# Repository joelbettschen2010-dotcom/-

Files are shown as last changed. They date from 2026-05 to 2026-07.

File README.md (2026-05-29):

# 🚲 Velo Navi Schweiz

Eine Velo-/E-Bike-Navigations-App für die **ganze Schweiz**. Sie schlägt
mehrere Routen vor, berechnet die Fahrzeit **physikalisch** (inkl. Steigung
und Velo-Typ) und **lernt dein persönliches Tempo** aus deinem Feedback nach
jeder Fahrt.

Läuft als **einzelne Web-App ohne Server** – einfach `index.html` im Browser
öffnen (oder in der Claude-App als Vorschau).

## Funktionen

- **Ganze Schweiz** – Ortssuche über swisstopo/geo.admin.ch oder Klick auf die Karte.
- **Mehrere Routenvorschläge** – Alternativrouten + optional andere Fahrstile als Varianten.
- **Velo-Typ wählbar** – **Velo**, **E-Bike 25** (Abregelung 25 km/h),
  **E-Bike 45** (S-Pedelec, 45 km/h). Der Motor wird im Zeitmodell berücksichtigt.
- **Routen-Stil** – **Trekking/Stadt**, **Rennvelo**, **Gravel**, **MTB Trail**
  (eigene BRouter-Profile mit passenden Untergründen).
- **Höhenberechnung** – die Steigung jedes Streckenabschnitts fliesst in die Zeit ein
  (bergauf dauert länger, bergab schneller), mit Höhenprofil-Diagramm.
- **Routenbeschreibung** – Anteil Strasse / Veloweg / Schotter / Wald / Trail,
  Höhenmeter ↑↓ und maximale Steigung pro Route.
- **Tempo-Feedback & Kalibrierung** – nach jeder Fahrt angeben „war schneller/langsamer".
  Die App passt den Tempo-Faktor **pro Velo-Typ** an und speichert ihn lokal.
- **GPX-Export** je Route.

## Bedienung

1. `index.html` im Browser öffnen.
2. Start & Ziel eingeben (Suche) oder auf die Karte klicken.
3. Velo-Typ, Routen-Stil und Tretleistung wählen.
4. **Routen berechnen** drücken.
5. Eine Route anklicken → Karte + Höhenprofil. Mit **🏁 Gefahren** Feedback geben.

## Wie die Zeit berechnet wird

Pro Streckenabschnitt wird die Gleichgewichts­geschwindigkeit aus der
Leistungs­gleichung gelöst:

```
P = v · ( Crr·m·g·cosθ  +  m·g·sinθ  +  ½·ρ·CdA·v² ) / η
```

- `Crr` Rollwiderstand (je nach Untergrund: Asphalt … Trail)
- `m` Gesamtmasse (Fahrer + Velo, je nach Velo-Typ)
- `θ` Steigungswinkel aus den Höhendaten
- `CdA` Luftwiderstandsfläche, `ρ` Luftdichte, `η` Antriebs­wirkungsgrad
- `P` = Tretleistung **+ Motorleistung** (E-Bike, nur unterhalb der Abregelgeschwindigkeit)

Das Ergebnis wird mit deinem persönlichen **Kalibrierungs­faktor** multipliziert.

## Datenquellen

- **Karten:** [swisstopo](https://www.swisstopo.admin.ch) WMTS (Landeskarte / Satellit)
- **Routing & Höhen:** [BRouter](https://brouter.de) (OSM-basiert, kostenlos)
- **Ortssuche:** geo.admin.ch SearchServer
- **Karten-Engine:** [Leaflet](https://leafletjs.com)

Alle Dienste sind kostenlos und benötigen keinen API-Schlüssel. Es ist eine
Internet­verbindung nötig (Kacheln, Routing, Suche).

## Dateien

| Datei | Zweck |
|---|---|
| `index.html` | Aufbau / UI |
| `style.css` | Gestaltung (dunkles Theme, responsiv) |
| `app.js` | Karte, Routing, Zeitmodell, Höhenprofil, Feedback |

## Hinweise / Limiten

- Der öffentliche BRouter-Server hat eine Fair-Use-Begrenzung.
- Die berechnete Zeit ist eine Schätzung ohne Pausen; mit Feedback wird sie genauer.
- E-Bike-Reichweite/Akku wird (noch) nicht modelliert.

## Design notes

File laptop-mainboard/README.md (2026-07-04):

# Laptop-Mainboard — AMD AM5 im HP-EliteBook-850-G7-Chassis (Rev B)

Komplettes KiCad-8-Projekt für ein Laptop-Mainboard mit **gesockelter**
Desktop-CPU (AM5) statt verlöteter Mobile-CPU.

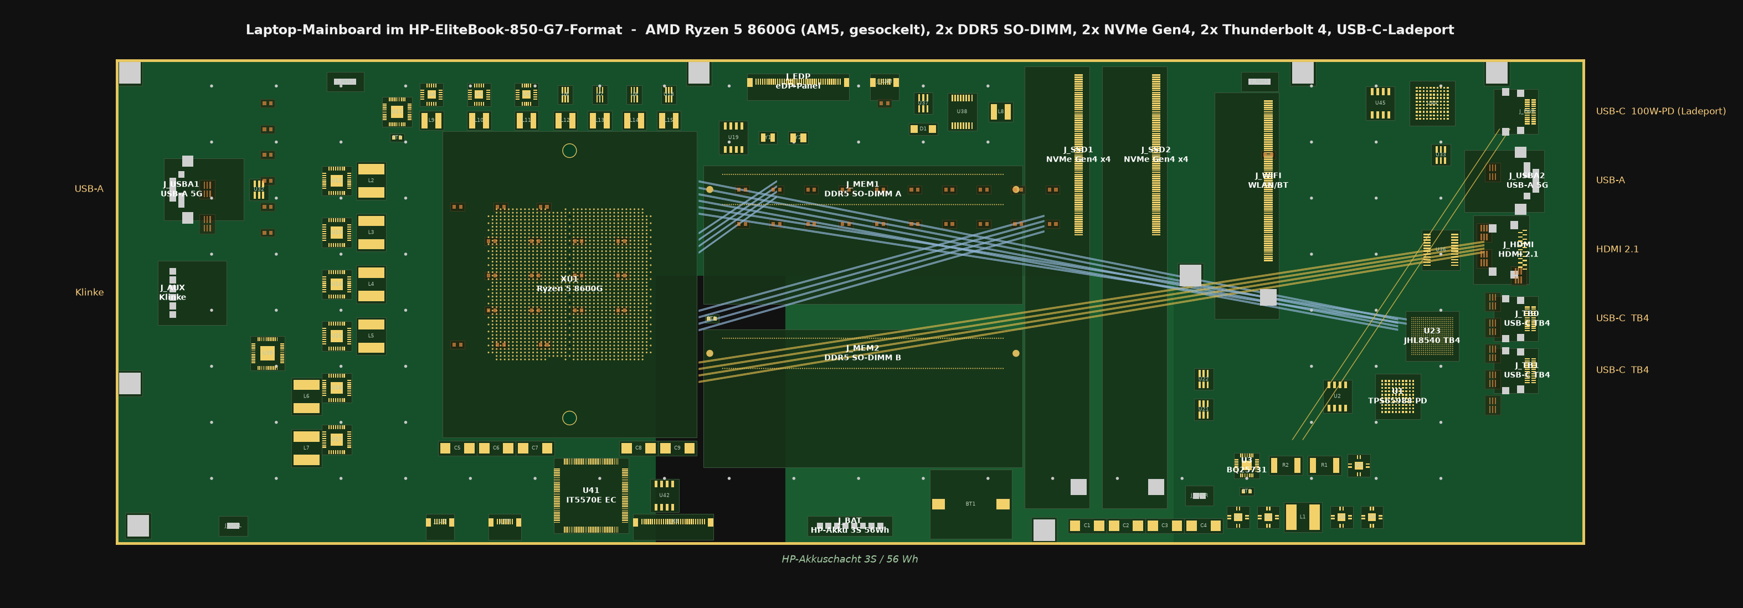
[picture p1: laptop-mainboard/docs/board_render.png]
Board


Konzept

## Eckdaten

| Bereich | Umsetzung |
|---|---|
| CPU | **AMD Ryzen 5 8600G** (x86-64, Zen 4, 6C/12T, Radeon 760M) im **AM5-Sockel LGA-1718** — wechselbar wie beim Desktop-PC, per cTDP auf 35–45 W gedrosselt |
| Chipsatz | **keiner** (chipsatzlos wie DeskMini X600) — alle I/O direkt vom SoC |
| Pinbelegung | **alle 1718 AM5-Pins benannt** (docs/am5_pinmap.csv, WikiChip/Wikimedia Public Domain); 1708 Sockelpads im Board mit echtem Signal-Netz |
| RAM | 2× DDR5 **SO-DIMM** (1 DIMM pro Kanal, bis DDR5-5600, max. 96 GB) |
| Storage | 2× **M.2 2280 NVMe**, je PCIe 4.0 ×4, getrennt schaltbare 3.3-V-Schienen |
| WLAN | 1× M.2 2230 E-Key (PCIe ×1 + USB 2.0), z. B. Wi-Fi 7 Modul |
| Thunderbolt | 2× **Thunderbolt 4** über **Intel JHL8540** (Maple Ridge), PCIe ×4 Uplink + 2× DP-1.4-Sink |
| Laden | **Eigener USB-C-Ladeport** (100 W USB-PD, TPS65987D) an der Barrel-Jack-Position → **BQ25731** → HP-Akku 3S/56 Wh (NVDC) |
| USB | 2× USB-A 5 Gbit (je einer links/rechts, wie 850 G7) |
| Netzwerk | WLAN/BT über M.2-Modul (das Original hat kein RJ45) |
| Video | HDMI 2.1 (nativ vom SoC, TPD12S016-Companion), intern eDP 1.4 (2 Lanes) |
| Audio | Realtek ALC256, 3.5-mm-Kombiklinke (AUX), 2× 2-W-Lautsprecher |
| Kleinteile | Blatt 10: MLCC-Bänke, 11 ESD-Arrays, USB2-Chokes, Straps (beidseitige Bestückung) |
| EC | ITE IT5570E: Power-Sequencing, Tastatur 8×18, Akku-SMBus, 2× Lüfter |
| Board | 340 × 112 mm, 8 Lagen, Portlayout/Umriss für HP EliteBook 850 G7 (docs/elitebook.md) |

## Projektstruktur

```
laptop-mainboard/
├── kicad/                     KiCad-8-Projekt (öffnen: laptop-mainboard.kicad_pro)
│   ├── laptop-mainboard.kicad_sch   Übersichtsblatt (Hierarchie)
│   ├── 01_power_pd.kicad_sch        USB-PD, Laderegler, Systemschienen
│   ├── 02_vrm_cpu.kicad_sch         CPU-VRM (SVI3, 4+2 Phasen)
│   ├── 03_cpu_am5.kicad_sch         AM5-Sockel, BIOS-Flash, RTC
│   ├── 04_memory.kicad_sch          2× DDR5 SO-DIMM
│   ├── 05_storage.kicad_sch         2× M.2 NVMe + WLAN
│   ├── 06_usb_tb4.kicad_sch         Thunderbolt 4 + USB
│   ├── 07_ladeport.kicad_sch        USB-C-Ladeport 100W (TPS65987D)
│   ├── 08_display.kicad_sch         eDP, HDMI, Backlight, Webcam
│   ├── 09_audio_sd_ec.kicad_sch     Audio, Embedded Controller
│   ├── 10_kleinteile.kicad_sch      Entkopplung, ESD, Filter, Straps
│   ├── laptop-mainboard.kicad_pcb   Board: Umriss, Platzierung, Lagen, Zonen
│   ├── lm.kicad_sym                 Symbolbibliothek
│   └── laptop_mainboard.pretty/     Footprints (inkl. LGA-1718, SO-DIMM 262)
├── docs/
│   ├── architektur.md         Blockdiagramm, PCIe-/USB-/Display-Budget
│   ├── power.md               Schienen, Power-Budget, Sequencing
│   ├── layout.md              Lagenaufbau, Floorplan, Routing-Regeln
│   ├── elitebook.md           EliteBook-850-G7-Einbau: passt/zu messen
│   ├── am5_pinmap.csv         Alle 1718 AM5-Pins mit Signalnamen
│   ├── grenzen.md             Was dieses Projekt (bewusst) nicht abdeckt
│   ├── board_render.png       Bestückungsansicht (generiert)
│   └── bom.csv                Stückliste (150 Positionen)
└── tools/
    └── gen_all.py             Generator — erzeugt alle KiCad-Dateien
```

**Wichtig:** Die KiCad-Dateien werden generiert. Änderungen in
`tools/kicadgen/boarddata*.py` (Schaltung) bzw. `tools/gen_all.py`
(Floorplan) vornehmen und `python3 tools/gen_all.py` ausführen.

## Warum diese Architektur?

- **Gesockelte CPU:** AMD verkauft Mobile-CPUs nur als BGA (verlötet). Der
  Wunsch „normaler PC-Sockel statt löten" führt zwingend zum Desktop-Sockel
  AM5. Der Ryzen 5 8600G ist die effizienteste AM5-Wahl: monolithischer
  Phoenix-Die (kein Chiplet-Idle-Verbrauch), starke iGPU, offizieller
  cTDP-Bereich 35–65 W.
- **Chipsatzlos:** Ein B650-Chipsatz würde ~7 W dauerhaft verbrauchen. Der
  8600G hat genug eigene Lanes/USB-Ports für alle geforderten Anschlüsse.
- **Echtes Thunderbolt 4:** AMD kann nur USB4. Für zertifizierbares TB4 sitzt
  ein Intel JHL8540 auf dem Board (PCIe ×4 + 2× DisplayPort vom SoC).
- **NVDC-Laden:** Der BQ25731 lässt das System direkt aus dem 100-W-Netzteil
  laufen und lädt den Akku mit dem Rest — Standard-Topologie moderner Laptops.

## Ehrlichkeit / Reifegrad

Rev B ist ein **weit ausgearbeiteter Prototyp-Stand**: vollständige
Systemarchitektur, echte AM5-Pinbelegung (Public-Domain-Quelle) an allen
Sockelpads, Kleinteile (Entkopplung/ESD/Filter) auf eigenem Blatt,
kollisionsfreier beidseitiger Floorplan im EliteBook-Format mit Zonen,
Stitching-Vias und Routing-Korridoren. **Noch nicht bestellbar:** das
DRC-saubere Feinrouting aller ~640 Netze, die Verifikation der
Community-Pinmap und die HP-Mechanik-/FPC-Vermessung stehen aus —
Details in [docs/grenzen.md](docs/grenzen.md) und
[docs/elitebook.md](docs/elitebook.md).

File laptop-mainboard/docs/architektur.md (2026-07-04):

# Systemarchitektur

## Blockdiagramm

```mermaid
flowchart LR
    subgraph SOC["Ryzen 5 8600G (AM5-Sockel)"]
        CPU[Zen4 6C/12T]
        GPU[Radeon 760M]
        IO[SoC-I/O]
    end

    MEM1[SO-DIMM A DDR5] ---|Kanal A| SOC
    MEM2[SO-DIMM B DDR5] ---|Kanal B| SOC

    SOC ---|PCIe4 x4 P0| SSD1[M.2 NVMe 1]
    SOC ---|PCIe4 x4 P1| SSD2[M.2 NVMe 2]
    SOC ---|PCIe3 x4 P2 + 2x DP1.4| TB[JHL8540 TB4]
    TB --- TB0[USB-C TB4 #0]
    TB --- TB1[USB-C TB4 #1]
    SOC ---|PCIe x1 G2 + USB2| WIFI[M.2 E-Key WLAN]
    SOC ---|USB3 Gen1 x2| USBA[2x USB-A]
    SOC ---|HDMI 2.1| HDMI[HDMI-Buchse]
    SOC ---|eDP 1.4 2L| PANEL[15.6 Panel]
    SOC ---|HDA| AUD[ALC256] --- JACK[3.5mm AUX]
    SOC ---|eSPI| EC[IT5570E EC]
    PWR[USB-C-Ladeport 100W] --- PD2[TPS65987D]
    PD2 ---|+VBUS 20V| CHG[BQ25731 Lader] --- BAT[HP-Akku 3S 56Wh]
    PD[TPS65988] --- TB0
    PD --- TB1
    CHG ---|+VSYS| VRM[VRM 4+2 Phasen SVI3] --- SOC
```

## PCIe-Lane-Budget (Phoenix, 20× Gen4)

| SoC-Port | Breite | Gen | Verwendung |
|---|---|---|---|
| P0 | ×4 | 4 | M.2 NVMe #1 |
| P1 | ×4 | 4 | M.2 NVMe #2 |
| P2 | ×4 | 3 | Thunderbolt-Controller JHL8540 |
| G0 | ×1 | — | frei (Reserve) |
| G1 | ×1 | — | frei (Reserve) |
| G2 | ×1 | 3 | WLAN M.2 E-Key |
| Referenztakte | — | — | 6× 100 MHz vom SoC-GPP-Clocktree (PE_CLK0…5) |

## USB-Portzuordnung

| SoC-Port | Geschwindigkeit | Ziel |
|---|---|---|
| U3G2_1 / USB2_1 | 10G / 480M | USB-A #1 (links) |
| U3G2_2 / USB2_2 | 10G / 480M | USB-A #2 (links) |
| USB2_3 | 480M | USB-C-Ladeport (Datenpfad) |
| USB2_5 / USB2_6 | 480M | TB4-Ports (USB-2.0-Pfad) |
| USB2_7 | 480M | WLAN/Bluetooth |
| USB2_8 | 480M | Webcam |

## Display-Budget (4 Pipes des SoC)

1. **eDP 1.4, 2 Lanes** → internes 15.6"-Panel (bis 2560×1440@60)
2. **HDMI 2.1** → externe Buchse (TMDS direkt, DDC/CEC über TPD12S016)
3. **DP0** → JHL8540 DP-IN 0 (Thunderbolt-Ausgabe Port 0)
4. **DP1** → JHL8540 DP-IN 1 (Thunderbolt-Ausgabe Port 1)

## Management-Busse

- **eSPI**: SoC ↔ EC (IT5570E)
- **SVI3**: SoC ↔ VRM-Controller MP2857 (SVC/SVD/SVT)
- **I3C/SMBus (SPD_HSCL/HSDA)**: SoC ↔ DIMM-SPD-Hubs
- **I2C (EC)**: Akku (Smart Battery), Laderegler BQ25731, PD-Controller TPS65988
- **I2C (PD↔TB)**: TPS65988 ↔ JHL8540 (Alternate-Mode-Aushandlung)

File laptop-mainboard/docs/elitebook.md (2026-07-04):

# Anpassung an das HP EliteBook 850 G7 (15.6")

Das Board ist auf den Einbau in ein EliteBook-850-G7-Chassis ausgelegt.

## Gehäuse-Randdaten

| Grösse | Wert |
|---|---|
| Chassis aussen | 358.5 × 233.9 × 17.9 mm |
| Board-Umriss (dieses Projekt) | 340 × 112 mm, oberer Gehäusebereich |
| Akku | HP-Original 3S / 56 Wh (z. B. HP L35766-005), Schacht unterhalb |
| Display | 15.6" eDP (30/40-polig) — **elektrisch kompatibel** (eDP ist Standard) |

## Portlayout (wie 850 G7)

**Rechte Kante, hinten → vorn (nach Foto des Originalgeräts):**

| Original | Dieses Board |
|---|---|
| Netzkabel-Anschluss (Barrel) | **USB-C-Ladeport 100W-PD** (J_PWR, eigener TPS65987D) — an exakt dieser Position |
| USB 3.1 Gen1 (USB-A) | USB-A 5G (J_USBA2) |
| HDMI | HDMI 2.1 (J_HDMI) |
| 2× USB-C Thunderbolt nebeneinander | 2× USB-C Thunderbolt 4 (J_TB0, J_TB1 am JHL8540) |
| Optionaler SIM-Slot | nicht bestückt (kein WWAN) |

**Linke Kante, hinten → vorn:** Diebstahlsicherung (mechanisch, kein Bauteil),
USB-A 5G mit Ladefunktion (J_USBA1), 3.5-mm-Kombiklinke (J_AUX).
Das Gerät hat **kein RJ45** — Netzwerk über das WLAN-Modul oder TB4-/USB-Adapter.

## Was direkt passt und was verifiziert werden muss

| Komponente | Status |
|---|---|
| Display (eDP) | ✅ Standard-Schnittstelle, 40-Pin-I-PEX vorgesehen; HP-Kabelbelegung gegen eDP-Standard prüfen |
| Webcam | ✅ USB 2.0 — Belegung des HP-Displaykabels ausmessen |
| Lüfter | ✅ 5V-PWM-Anschlüsse vorgesehen, Stecker ggf. umpinnen |
| Lautsprecher | ✅ 2× 2W an ALC256 |
| Akku | ⚠️ HP nutzt einen proprietären Stecker + Smart-Battery-SMBus; **Pinout muss am Original-Board ausgemessen werden** (J_BAT ist dafür vorgesehen: 2×BAT+, 2×GND, SCL, SDA, THERM, PRES#) |
| Tastatur | ⚠️ HP-Matrix-FPC — Zuordnung KSI/KSO **muss per Multimeter am Original ausgemessen** und in der EC-Firmware hinterlegt werden |
| Touchpad/Clickpad | ⚠️ I2C-HID üblich — Belegung des FPC verifizieren |
| Fingerprint/NFC | ❌ nicht vorgesehen |
| Umriss + Schraublöcher | ⚠️ **Muss am realen Chassis ausgemessen werden** (siehe unten) |

## Erkenntnisse aus dem Foto des Original-Mainboards

Das vom Nutzer gelieferte Foto der Originalplatine (Unterseite, mit
Heatpipe) zeigt die internen Anschluss-Positionen — fuer die naechste
Revision des Floorplans zu uebernehmen:

| Original (Silkscreen) | Position (Draufsicht) | Dieses Board |
|---|---|---|
| DC (Ladebuchse) | rechts hinten bei den Ports | ✅ J_PWR dort |
| SSD (M.2) | links | ⚠️ bei uns mittig-rechts (AM5-Sockel braucht die linke Haelfte) |
| WLAN (M.2 2230) | vorn rechts | ⚠️ bei uns mittig — umziehen sinnvoll |
| eDP + USB (Board-zu-Board) | rechte Kante | ⚠️ eDP bei uns oben Mitte |
| FAN | rechts (grosser Luefter-Ausschnitt oben rechts!) | ✅ J_FAN2 rechts oben |
| BATT | unten Mitte-rechts | ✅ J_BAT unten Mitte |
| FPR/B-L/Tastatur-FPCs | unten Mitte | ✅ |
| SPK | unten rechts | ✅ J_SPKR |
| RTC | unten links | ⚠️ bei uns rechts der DIMMs |
| S/C (Smartcard) | unten rechts aussen | nicht bestueckt |

Wichtigste Abweichung: Der Original-Umriss ist **kein Rechteck** — grosser
Luefter-Ausschnitt oben rechts, abgeschraegte Ecken, gestufte Vorderkante.
Unser AM5-Sockel + 2 SO-DIMMs brauchen jedoch deutlich mehr Flaeche als das
Original-Board (BGA-CPU + geloetetes RAM), daher nutzt unser Board bewusst
das volle Rechteck inkl. des originalen Luefter-/Freibereichs — der Kuehler
muss entsprechend als Custom-Loesung darueber liegen.

## Wichtig: Masse und Lochbild

HP veröffentlicht keine mechanischen Zeichnungen des Mainboards. Der
Board-Umriss (340 × 112 mm) und die 8 Befestigungslöcher in diesem Projekt
sind eine **fundierte Annäherung** an den verfügbaren Innenraum — kein
vermessenes Abbild. Vor einer Fertigung:

1. Original-Mainboard ausbauen, auf Flachbettscanner legen (1:1, 600 dpi),
   oder mit Messschieber Umriss + Lochpositionen aufnehmen.
2. Werte in `tools/gen_all.py` (Konstanten `X0/Y0/X1/Y1` + `MTG`-Positionen
   und Port-Y-Koordinaten) eintragen, `python3 tools/gen_all.py` ausführen.
3. Papier-/Karton-Probedruck des Umrisses ins Gehäuse legen.

Die Port-Positionen an der rechten Kante müssen auf ±0.5 mm mit den
Gehäuseausschnitten fluchten — auch diese Y-Koordinaten stammen aus Fotos
des Geräts, nicht aus einer Zeichnung, und sind zu verifizieren.

## Kühlung

Das 850 G7 kühlt eine 15–25-W-CPU mit einem flachen Blower. Der gesockelte
8600G (35–45 W) braucht **deutlich mehr**: Vapor-Chamber über dem Sockel,
2 Heatpipes, beide Lüfterpositionen bestückt. Die Bauhöhe des Sockels
(CPU + ILM ≈ 7.5 mm) plus Kühler sprengt die originalen 17.9 mm —
realistisch ist ein **modifizierter/erhöhter Bodendeckel (+6–8 mm)**.
Das ist die härteste mechanische Einschränkung dieses Umbaus.

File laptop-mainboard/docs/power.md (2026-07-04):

# Stromversorgung

## Eingangs- und Ladepfad

```
USB-C-Ladeport J_PWR (20V/5A, 100W PD, an der Barrel-Jack-Position)
   └─ TPS65987D (PD-Aushandlung, interner Pfad-FET, 5A, Dead-Battery-Boot)
        └─ +VBUS_IN ── R2 (10 mΩ, ACP/ACN) ── BQ25731 Buck-Boost (Q1–Q4 + L1 3.3µH)
             ├─ +VSYS (NVDC-Systemschiene, 9…13V)
             └─ Q5 (BATFET) ── R1 (10 mΩ, SRP/SRN) ── +VBAT (HP-Akku 3S)
```

- **Akku:** HP-Original 3S Li-Ion, 11.55 V nominal, 56 Wh (EliteBook 850 G7), Smart-Battery-SMBus am J_BAT.
- **NVDC:** System läuft immer aus +VSYS; der Lader teilt die 100 W dynamisch
  zwischen System und Akku auf (Input-Current-Limit über ILIM_HIZ + SMBus).
- Die beiden TB4-Ports sind Source-only (je 5 V/3 A über TPS65988 aus +5V).

## Schienenübersicht

| Schiene | Quelle | Spannung | Last (max.) | Verbraucher |
|---|---|---|---|---|
| +VSYS | BQ25731 | 9–13 V (3S) | 100 W | VRM, Bucks, Backlight |
| +VDDCR_CPU | MP2857 + 4× MP86957 | 0.6–1.4 V (SVI3) | 60 A | CPU-Kerne |
| +VDDCR_SOC | MP2857 + 2× MP86957 | 0.8–1.2 V (SVI3) | 30 A | SoC/iGPU |
| +5V | MPQ8633B (U4) | 5 V | 8 A | DIMM-Bulk, USB-VBUS, Lüfter, HDA |
| +3V3 | MPQ8633B (U5) | 3.3 V | 8 A | LAN, Audio, TB-I/O, Panel |
| +3V3_ALW | MPQ8633B (U9) | 3.3 V | 2 A | EC, PD-Controller (S5-Domäne) |
| +1V8 | TPS62823 (U6) | 1.8 V | 3 A | BIOS-Flash, VDD_MISC, VDD_1V8 |
| +1V1_MEM | TPS62823 (U18) | 1.1 V | 4 A | VDDIO_MEM (SoC-Seite) |
| +1V05_TB | TPS62823 (U7) | 1.05 V | 3 A | JHL8540 I/O |
| +0V88_TB | TPS62823 (U8) | 0.88 V | 3 A | JHL8540 Core |
| +VLCD | SY6280 (U37) | 3.3 V | 2 A | Panel-Logik |
| +VBL | MP3389 (U38) | ~19 V | 1.2 A | Backlight-LEDs |
| VDD_RTC | ML1220 | 3 V | µA | RTC-Domäne |

DDR5-Besonderheit: VDD/VDDQ (1.1 V) der Module erzeugt der **PMIC auf dem
DIMM** aus +5V — das Board liefert nur 5 V Bulk + 3.3 V Management.

## Power-Budget (worst case)

| Verbraucher | Leistung |
|---|---|
| CPU-Package (cTDP 45 W, kurzzeitig 65 W) | 45–65 W |
| 2× DDR5 SO-DIMM | 8 W |
| 2× NVMe SSD | 16 W (Spitze) |
| JHL8540 + 2 TB-Ports (ohne Buspower) | 4 W |
| 2× RTL8125BG | 3 W |
| Display + Backlight | 8 W |
| USB-Buspower (2×A, 2×C) | 21 W (Spitze) |
| Rest (EC, Audio, SD, WLAN, Lüfter) | 5 W |
| **Summe Spitze** | **~110–130 W** → Akku puffert über 100 W hinaus (NVDC) |
| **Typisch (Office)** | **15–25 W** |

## Power-Sequencing (EC-gesteuert)

1. Akku oder PD vorhanden → +VSYS steht → U9 liefert **+3V3_ALW** → EC bootet.
2. Power-Taste → EC: **EN_5V, EN_3V3** → PG_5V/PG_3V3 abwarten.
3. **EN_1V8**, **EN_VLCD**, TB_PWR_EN (1V05/0V88).
4. **EN_VRM** → MP2857 regelt VDDCR_CPU/SOC auf Boot-Spannung → VRM_PWRGD.
5. EC setzt **SYS_PWROK** und gibt **PM_PWR_BTN#** an den SoC.
6. SoC meldet Schlafzustände über **SLP_S3#/SLP_S5#** zurück; EC schaltet
   Schienen entsprechend (S3: nur +5V für DIMM-Selbstauffrischung + ALW).

Schutz: PROCHOT# (Lader ↔ SoC ↔ VRM), THERMTRIP# → EC schaltet hart ab,
3 NTCs (CPU, VRM, Lader) + Akku-Thermistor am EC-ADC.

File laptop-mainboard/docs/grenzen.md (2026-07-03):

# Stand des Designs und verbleibende Grenzen

## Was seit Rev A dazugekommen ist (Rev B)

1. **Echte AM5-Pinbelegung:** Alle 1718 Sockelpins sind jetzt einzeln
   benannt — Quelle ist die Public-Domain-Pinmap von WikiChip
   (Wikimedia Commons, „Socket AM5 pinmap.svg", Autor QuietRub).
   Tabelle: `docs/am5_pinmap.csv`. Der Sockel-Footprint trägt die echten
   Padnamen (A1…) und **1708 Pads haben ihr echtes Signal als Netz** im
   Board (VSS→GND, VDDCR, MAA/MAB/MBA/MBB-Speicherkanäle, PCIE_TX/RX[27:0],
   DP0–2, USBC0–2, SPI, eSPI, AZ/HDA …).
2. **Kleinteile:** Blatt 10 mit MLCC-Bänken (VDDCR/SOC unter dem Sockel,
   Bottom-Side), Schienen-Entkopplung, 11 ESD-Arrays an allen externen
   Ports, USB2-Gleichtaktdrosseln, Pull-Up/Down-Straps. 48-MHz-Systemquarz
   ergänzt (X48M-Pins der Pinmap). Bestückung beidseitig (B.Cu-Parts).
3. **Mehr Routing:** GND-Stitching-Via-Raster, MDI-, DP-, PCIe-, HDMI- und
   DDR-Korridore als Differenzpaare, Netz-Zuordnung an allen Sockelpads.
4. **EliteBook-850-G7-Anpassung:** Umriss 340×112 mm, Portreihenfolge wie
   beim Original (USB-C-PD statt Barrel-Jack), 3S-56-Wh-Akku, HP-FPC-
   Steckplätze — Details und offene Messpunkte in `docs/elitebook.md`.

## Was weiterhin fehlt — ehrlich gesagt

1. **Pinmap-Verifikation:** Die WikiChip-Pinmap ist Community-Arbeit,
   kein AMD-Originaldokument. Vor Fertigung gegen ein echtes AM5-Board
   (Beeper/Multimeter, mind. Power/GND + einige Signale) gegenprüfen.
   Die PCIe-Lane→Port-Bifurcation (welche 4er-Gruppe zu SSD/TB wird)
   ist firmwareabhängig und muss mit dem AGESA-Port abgestimmt werden.
2. **Feinrouting:** Die Korridore zeigen Topologie und Lagen; das
   DRC-saubere Ausrouten aller ~640 Netze mit DDR5-Längenabgleich
   (±0.1 mm) und SI-Simulation bleibt Monate Ingenieursarbeit.
   Ohne dieses Feinrouting ist das Board **nicht bestellbar**.
3. **HP-Proprietäres:** Akku-, Tastatur-, Touchpad- und Displaykabel-
   Pinouts müssen am Originalgerät ausgemessen werden (docs/elitebook.md).
   Chassis-Umriss und Lochbild sind Annäherungen bis zum Scan des Originals.
4. **Firmware:** UEFI/AGESA-Port für chipsatzloses AM5, EC-Firmware
   (inkl. HP-Tastaturmatrix), TPS65988-/JHL8540-Konfigurationsbinaries —
   ausdrücklich noch nicht Teil des Auftrags.
5. **Mechanik/Thermik:** 35–45 W gesockelt in einem 17.9-mm-Chassis
   erfordert einen erhöhten Bodendeckel und eine Custom-Vapor-Chamber.
6. **Zulassung:** TB4-/USB-IF-Zertifizierung, CE/FCC, UN38.3.

## Realistische Einschätzung bis zum Prototyp

| Schritt | Aufwand |
|---|---|
| Dieser Stand (Architektur, Pinbelegung, Kleinteile, Floorplan) | ✔ |
| Pinmap-Verifikation + Detail-Schaltplan-Review | 2–4 Wochen |
| Feinrouting + SI-Simulation | 2–4 Monate |
| Chassis-Vermessung + Mechanik (Kühler, Bodendeckel) | 4–8 Wochen |
| Prototyp + Bring-up + BIOS/EC-Port | 3–6 Monate |
| Budget | grob 50–150 k€ |

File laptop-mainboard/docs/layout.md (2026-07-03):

# PCB-Layout

## Board

- **Abmessung:** 340 × 112 mm, 8 Befestigungslöcher M2.5, ausgelegt auf das
  HP-EliteBook-850-G7-Chassis (358.5 × 233.9 mm aussen); HP-Akkuschacht
  unterhalb. Umriss/Lochbild vor Fertigung am Chassis verifizieren
  (docs/elitebook.md).
- **Dicke:** 1.6 mm (bei Bedarf 1.2 mm mit angepasstem Lagenaufbau).

## Lagenaufbau (8 Lagen)

| Lage | Funktion |
|---|---|
| F.Cu | Bauteile, kurze Anbindungen, HDMI-TMDS |
| In1.Cu | DDR5-Signale + VDDCR-Zonen unter dem Sockel |
| In2.Cu | **GND-Plane 1** (durchgehend) |
| In3.Cu | Power: +VSYS |
| In4.Cu | Power: +5V / +3V3 (gesplittet) |
| In5.Cu | **GND-Plane 2** (durchgehend) |
| In6.Cu | PCIe-Gen4-Paare, TB-Paare |
| B.Cu | GND + restliche Signale, Entkopplung unter dem Sockel |

Jede Highspeed-Lage referenziert direkt auf eine GND-Plane.

## Floorplan

```
+------------------------------------------------------------------+
| Lüfter L   Bucks 5V/3V3/…   eDP  Webcam  BL   [SSD1][SSD2] Lüfter R|
| RJ45#1  PHY1        +--------+  BIOS   [M.2 vertikal]  JHL8540 TB0|
| RJ45#2  PHY2  VRM   |  AM5   |  SO-DIMM A       WLAN   TPS65988 TB1|
| USB-A#1       4+2Ph |LGA-1718|  SO-DIMM B        SD-Ctrl  Mux USBC2|
| USB-A#2  Audio      +--------+  RT1                HDMI     USBC3  |
| Klinke   ALC256  Caps   EC  ECFlash BT1  Lader BQ25731   SD-Slot  |
| Spk L  Lid TP  KB-FPC  [Akku-Stecker]  Bulk-Caps  FETs+L   Spk R  |
+------------------------------------------------------------------+
```

Leitidee: **kurze Highspeed-Wege** — Sockel mittig-links, DIMMs direkt
rechts daneben (Kanal A/B symmetrisch), M.2 und TB-Silizium zwischen Sockel
und rechter Portleiste; Ethernet-PHYs direkt hinter den RJ45-Buchsen links.
VRM links vom Sockel mit kurzem Pfad in die Sockel-Power-Pins,
Eingangs-/Ladeteil unten rechts beim Ladeport.

## Routing-Regeln

| Signalklasse | Impedanz | Regeln |
|---|---|---|
| DDR5 (CA/DQ/DQS/CK) | 40 Ω SE / 80 Ω diff | Byte-Lane-Skew ±0.5 mm, CA-Fly-by, Referenz In2 |
| PCIe Gen4 | 85 Ω diff | Intra-Pair ±0.1 mm, max. 2 Via-Paare, Ground-Stitching |
| TB4/USB4 40G | 85 Ω diff | < 60 mm bis Buchse, keine Stubs, GND-Vias ≤ 1 mm neben jedem Signal-Via |
| USB3 Gen2 | 90 Ω diff | ESD-Dioden im Pfad, < 100 mm |
| HDMI TMDS | 100 Ω diff | Längenabgleich Paar ±0.15 mm |
| MDI (Ethernet) | 100 Ω diff | < 25 mm zum Magjack, Bob-Smith-Cap an MCT |
| VRM → Sockel | — | Kupferflächen ≥ 6 mm², Via-Farmen, Sense-Leitungen differentiell zur Die-Sense |

Im Board sind repräsentative **Routing-Korridore** (In1/In6) als
Differenzpaare eingezeichnet; das Feinrouting folgt diesen Korridoren.

## Kühlung / Mechanik

- Sockelzone: 100 × 75 mm für Kühler (Vapor-Chamber + 2 Heatpipes zu beiden
  Lüftern) freihalten — Kommentar-Layer im Board.
- AM5-ILM: Standard-Backplate; bei 45 W reicht ein 25-mm-Kühlkörperprofil,
  Bauhöhe gesamt ≈ 12 mm über Board → Gehäusedicke ~20 mm einplanen.
- VRM-Stages und Ladewandler über Wärmeleitpads an die Bodenplatte koppeln.

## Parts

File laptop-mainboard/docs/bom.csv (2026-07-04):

Referenz | Wert | Beschreibung | Hersteller-Teilenummer | Footprint
U1 | TPS65988DH | Dual-USB-C-PD-Controller fuer die beiden TB4-Ports (je 15W Source) | Laden laeuft ueber den separaten Ladeport (Blatt 7) | TI TPS65988DHRSHR | BGA96_9x9
U2 | W25Q80DV_PDCFG | PD-Konfigurations-Flash 1 MB | Winbond W25Q80DVSNIG | SOIC8
J_BAT | AkkuStecker_HP_3S | Akku-Stecker fuer HP-Originalakku 3S / 56 Wh (EliteBook 850 G7, HP L35766-005) - Pinout am Originalboard verifizieren! | HP-kompatibel (Reverse-Engineering noetig) | CONN_BAT8_2mm
U3 | BQ25731 | Buck-Boost-NVDC-Laderegler, 3S-Akku (CELL=3S), 20V/5A Eingang | TI BQ25731RSNR | QFN32_4x4
L1 | L_3u3_IHLP | Speicherdrossel 3.3 uH / 12 A | Vishay IHLP-2828CZ-3R3 | IND_7x7
R1 | R_SHUNT_10m | Shunt 10 mOhm Ladestrommessung (BATFET Q5 -> Akku) | Bourns CSS2H-2512R-L100F | R_2512
R2 | R_SHUNT_10m_IN | Shunt 10 mOhm Eingangsstrommessung (ACP/ACN) | Bourns CSS2H-2512R-L100F | R_2512
Q1 | SiSS22DN | 30V N-FET Ladewandler | Vishay SiSS22DN | PowerPAK_1212
Q2 | SiSS22DN | 30V N-FET Ladewandler | Vishay SiSS22DN | PowerPAK_1212
Q3 | SiSS22DN | 30V N-FET Ladewandler | Vishay SiSS22DN | PowerPAK_1212
Q4 | SiSS22DN | 30V N-FET Ladewandler | Vishay SiSS22DN | PowerPAK_1212
Q5 | SiSS22DN | 30V N-FET Ladewandler | Vishay SiSS22DN | PowerPAK_1212
L9 | L_1uH | Speicherdrossel 1uH | TDK SPM4020T-1R0M | IND_4x4
L10 | L_1uH | Speicherdrossel 1uH | TDK SPM4020T-1R0M | IND_4x4
U4 | MPQ8633B | Synchronbuck 5V/8A Systemschiene | MPS MPQ8633BGLE | QFN20_3x4
U5 | MPQ8633B | Synchronbuck 3.3V/8A Systemschiene | MPS MPQ8633BGLE | QFN20_3x4
U9 | MPQ8633B | Synchronbuck 3.3V/2A Always-On (EC, PD) | MPS MPQ8633BGLE | QFN20_3x4
U6 | TPS62823 | Buck 1.8V/3A (BIOS, VDD_MISC) | TI TPS62823DMQR | DFN6_2x2
U7 | TPS62823 | Buck 1.05V/3A Thunderbolt | TI TPS62823DMQR | DFN6_2x2
U8 | TPS62823 | Buck 0.88V/3A Thunderbolt-Core | TI TPS62823DMQR | DFN6_2x2
U18 | TPS62823 | Buck 1.1V/4A VDDIO_MEM (SoC-Seite) | TI TPS62823DMQR | DFN6_2x2
L11 | L_1uH | Speicherdrossel 1uH | TDK SPM4020T-1R0M | IND_4x4
L12 | L_470n | Speicherdrossel 470n | TDK SPM4020T-1R0M | IND_4x4
L13 | L_470n | Speicherdrossel 470n | TDK SPM4020T-1R0M | IND_4x4
L14 | L_470n | Speicherdrossel 470n | TDK SPM4020T-1R0M | IND_4x4
L15 | L_470n | Speicherdrossel 470n | TDK SPM4020T-1R0M | IND_4x4
C1 | 330u_Polymer | Polymer-Bulkkondensator 330uF/25V | Panasonic 25SVPF330M | CAP_7343
C2 | 330u_Polymer | Polymer-Bulkkondensator 330uF/25V | Panasonic 25SVPF330M | CAP_7343
C3 | 330u_Polymer | Polymer-Bulkkondensator 330uF/25V | Panasonic 25SVPF330M | CAP_7343
C4 | 330u_Polymer | Polymer-Bulkkondensator 330uF/25V | Panasonic 25SVPF330M | CAP_7343
U11 | MP2857_SVI3 | SVI3-Dual-Rail-VRM-Controller 4+2 Phasen | MPS MP2857GU | QFN40_5x5
C5 | 470u_Polymer | Polymer-Ausgangskondensator 470uF/2.5V | Panasonic 2R5TPE470M9 | CAP_7343
C6 | 470u_Polymer | Polymer-Ausgangskondensator 470uF/2.5V | Panasonic 2R5TPE470M9 | CAP_7343
U12 | MP86957_Stage | Smart-Power-Stage 70A (VDDCR_CPU) | MPS MP86957GQVT | QFN31_5x5
U13 | MP86957_Stage | Smart-Power-Stage 70A (VDDCR_CPU) | MPS MP86957GQVT | QFN31_5x5
U14 | MP86957_Stage | Smart-Power-Stage 70A (VDDCR_CPU) | MPS MP86957GQVT | QFN31_5x5
U15 | MP86957_Stage | Smart-Power-Stage 70A (VDDCR_CPU) | MPS MP86957GQVT | QFN31_5x5
U16 | MP86957_Stage | Smart-Power-Stage 70A (VDDCR_SOC) | MPS MP86957GQVT | QFN31_5x5
U17 | MP86957_Stage | Smart-Power-Stage 70A (VDDCR_SOC) | MPS MP86957GQVT | QFN31_5x5
L2 | L_220n_15A | VRM-Drossel 220nH/40A | Vishay IHLP-4040DZ-R22M | IND_7x7
L3 | L_220n_15A | VRM-Drossel 220nH/40A | Vishay IHLP-4040DZ-R22M | IND_7x7
L4 | L_220n_15A | VRM-Drossel 220nH/40A | Vishay IHLP-4040DZ-R22M | IND_7x7
L5 | L_220n_15A | VRM-Drossel 220nH/40A | Vishay IHLP-4040DZ-R22M | IND_7x7
L6 | L_220n_15A | VRM-Drossel 220nH/40A | Vishay IHLP-4040DZ-R22M | IND_7x7
L7 | L_220n_15A | VRM-Drossel 220nH/40A | Vishay IHLP-4040DZ-R22M | IND_7x7
C7 | 470u_Polymer | Polymer-Ausgangskondensator 470uF/2.5V | Panasonic 2R5TPE470M9 | CAP_7343
C8 | 470u_Polymer | Polymer-Ausgangskondensator 470uF/2.5V | Panasonic 2R5TPE470M9 | CAP_7343
C9 | 470u_Polymer | Polymer-Ausgangskondensator 470uF/2.5V | Panasonic 2R5TPE470M9 | CAP_7343
XU1 | AM5_Socket_R5-8600G | CPU-Sockel AM5 (LGA-1718) mit Ryzen 5 8600G, cTDP 35-45W | Pinbelegung: docs/am5_pinmap.csv (WikiChip, Public Domain) | Foxconn LGA1718 + AMD 100-100001237BOX | AM5_Socket_LGA1718
Y1 | XTAL_32K768 | RTC-Quarz 32.768 kHz | Epson FC-135 | XTAL_3215
Y2 | XTAL_48M | Systemtakt-Quarz 48 MHz (X48M) | TXC 7M-48.000MAAJ-T | XTAL_3225
U19 | W25Q256JW_BIOS | BIOS-SPI-Flash 32 MB, 1.8 V | Winbond W25Q256JWEIQ | SOIC8
J_MEM1 | SODIMM_DDR5 | DDR5 SO-DIMM Sockel 262-polig (1DPC) | TE 2309413-1 | SODIMM_DDR5_262
J_MEM2 | SODIMM_DDR5 | DDR5 SO-DIMM Sockel 262-polig (1DPC) | TE 2309413-1 | SODIMM_DDR5_262
J_SSD1 | M2_M-Key_2280 | M.2 M-Key 2280, PCIe 4.0 x4 NVMe | TE 2199230-4 | M2_M_2280
U21 | SY6280_LoadSW | Lastschalter 3.3V/2A | Silergy SY6280AAC | SOT23-5
J_SSD2 | M2_M-Key_2280 | M.2 M-Key 2280, PCIe 4.0 x4 NVMe | TE 2199230-4 | M2_M_2280
U22 | SY6280_LoadSW | Lastschalter 3.3V/2A | Silergy SY6280AAC | SOT23-5
J_WIFI | M2_E-Key_2230 | M.2 E-Key 2230 WLAN/BT (PCIe x1 + USB2) | TE 2199119-4 | M2_E_2230
U23 | JHL8540_TB4 | Intel Thunderbolt-4-Controller, 2 Ports (Maple Ridge) | Intel JHL8540 | BGA_10x9_JHL8540
J_TB0 | USB-C_TB4 | USB-C-Buchse Thunderbolt 4 / USB4 40G | JAE DX07S024WJ1R350 | USBC_24
J_TB1 | USB-C_TB4 | USB-C-Buchse Thunderbolt 4 / USB4 40G | JAE DX07S024WJ1R350 | USBC_24
J_USBA1 | USB-A_3G1 | USB-A-Buchse USB 3.2 Gen1 | Foxconn UEA1112C-4HK1-4F | USBA3_TH
J_USBA2 | USB-A_3G1 | USB-A-Buchse USB 3.2 Gen1 | Foxconn UEA1112C-4HK1-4F | USBA3_TH
U32 | SY6280_5V_SW | VBUS-Lastschalter 5V/2.1A mit Strombegrenzung | Silergy SY6280AAC | SOT23-5
U33 | SY6280_5V_SW | VBUS-Lastschalter 5V/2.1A mit Strombegrenzung | Silergy SY6280AAC | SOT23-5
U44 | TPS65987D_Lader | Single-USB-C-PD-Controller, 100W-Sink mit internem Pfad-FET -> Ladeeingang +VBUS_IN (Dead-Battery-faehig) | TI TPS65987DDHRSHR | BGA96_9x9
U45 | W25Q80DV_PD2CFG | Ladeport-Konfigurations-Flash 1 MB | Winbond W25Q80DVSNIG | SOIC8
J_PWR | USB-C_Ladeport | USB-C-Ladebuchse 100W (an der Barrel-Jack-Position des 850 G7), zusaetzlich USB-2.0-Daten | JAE DX07S024WJ1R350 | USBC_24
J_HDMI | HDMI-A | HDMI-Typ-A-Buchse (HDMI 2.1 TMDS/FRL vom SoC) | Molex 2086581051 | HDMI_A
U36 | TPD12S016 | HDMI-Companion: Pegelwandler DDC/CEC + HPD + 5V-Schalter + ESD | TI TPD12S016PWR | TSSOP24
J_EDP | eDP_40pol | eDP-1.4-Panelstecker 40-polig (15.6\" 2560x1440 IPS) | I-PEX 20455-040E-12 | FPC40_05
U37 | SY6280_VLCD | Panel-Lastschalter 3.3V/2A | Silergy SY6280AAC | SOT23-5
J_CAM | Webcam_Conn | Webcam-/Mikrofon-Stecker (USB2 + DMIC) | Molex 5051100692 | FPC6_05
U38 | MP3389_Backlight | Backlight-Boost-Treiber, 6 Straenge | MPS MP3389EF | TSSOP16EP
L8 | L_10u_Boost | Boost-Drossel 10uH | TDK SPM5030T-100M | IND_4x4
D1 | SS34_Schottky | Schottky-Diode 40V/3A | Vishay SS3P4 | SMA_DIODE
U39 | ALC256_Codec | HD-Audio-Codec mit 2W-Klasse-D-Verstaerker | Realtek ALC256-CG | QFN48_6x6
J_AUX | Klinke_3V5_TRRS | 3.5mm-Kombiklinke (Kopfhoerer + Headset-Mikrofon) | CUI SJ-43516-SMT-TR | TRRS_35
J_SPKL | Lautsprecher_L | Lautsprecher links 4 Ohm/2W | JST BM02B-SRSS-TB | CONN_SPK2
J_SPKR | Lautsprecher_R | Lautsprecher rechts 4 Ohm/2W | JST BM02B-SRSS-TB | CONN_SPK2
BT1 | ML1220 | RTC-Pufferzelle ML1220 (wiederaufladbar) | Panasonic ML-1220/F1AN | COIN_ML1220
RT1 | NTC_10k | NTC-Thermistor 10k (Temperatursensor) | Murata NCP18XH103F03RB | R_0603
RT2 | NTC_10k | NTC-Thermistor 10k (Temperatursensor) | Murata NCP18XH103F03RB | R_0603
RT3 | NTC_10k | NTC-Thermistor 10k (Temperatursensor) | Murata NCP18XH103F03RB | R_0603
U41 | IT5570E_EC | Embedded Controller: Tastatur, Power-Sequencing, Akku, Luefter | ITE IT5570E-128 | LQFP128_14x14
U42 | W25Q128_ECFW | EC-Firmware-Flash 16 MB | Winbond W25Q128JVSIQ | SOIC8
J_KB | Tastatur_FPC30 | FPC fuer HP-EliteBook-850-G7-Tastatur (Matrix-Zuordnung am Original ausmessen!) | HP-kompatibel, FPC 0.5mm | FPC30_05
J_TP | Touchpad_FPC8 | FPC fuer HP-Clickpad (I2C-HID, Pinout am Original verifizieren) | HP-kompatibel, FPC 0.5mm | FPC8_05
J_FAN1 | Luefter_4pol | Luefteranschluss 4-polig 5V PWM | JST BM04B-SRSS-TB | CONN_FAN4
J_FAN2 | Luefter_4pol | Luefteranschluss 4-polig 5V PWM | JST BM04B-SRSS-TB | CONN_FAN4
J_LID | Hallsensor_Lid | Deckelsensor (Hall) 3-polig | Molex 5051100392 | FPC6_05
C20 | 22u_0402 | MLCC 22uF/6.3V 0402 - VDDCR_CPU-Bank unter Sockel | Murata GRM155R60J226ME15 | R_0603
C21 | 22u_0402 | MLCC 22uF/6.3V 0402 - VDDCR_CPU-Bank unter Sockel | Murata GRM155R60J226ME15 | R_0603
C22 | 22u_0402 | MLCC 22uF/6.3V 0402 - VDDCR_CPU-Bank unter Sockel | Murata GRM155R60J226ME15 | R_0603
C23 | 22u_0402 | MLCC 22uF/6.3V 0402 - VDDCR_CPU-Bank unter Sockel | Murata GRM155R60J226ME15 | R_0603
C24 | 22u_0402 | MLCC 22uF/6.3V 0402 - VDDCR_CPU-Bank unter Sockel | Murata GRM155R60J226ME15 | R_0603
C25 | 22u_0402 | MLCC 22uF/6.3V 0402 - VDDCR_CPU-Bank unter Sockel | Murata GRM155R60J226ME15 | R_0603
C26 | 22u_0402 | MLCC 22uF/6.3V 0402 - VDDCR_CPU-Bank unter Sockel | Murata GRM155R60J226ME15 | R_0603
C27 | 22u_0402 | MLCC 22uF/6.3V 0402 - VDDCR_CPU-Bank unter Sockel | Murata GRM155R60J226ME15 | R_0603
C28 | 22u_0402 | MLCC 22uF/6.3V 0402 - VDDCR_CPU-Bank unter Sockel | Murata GRM155R60J226ME15 | R_0603
C29 | 22u_0402 | MLCC 22uF/6.3V 0402 - VDDCR_CPU-Bank unter Sockel | Murata GRM155R60J226ME15 | R_0603
C30 | 22u_0402 | MLCC 22uF/6.3V 0402 - VDDCR_CPU-Bank unter Sockel | Murata GRM155R60J226ME15 | R_0603
C31 | 22u_0402 | MLCC 22uF/6.3V 0402 - VDDCR_CPU-Bank unter Sockel | Murata GRM155R60J226ME15 | R_0603
C32 | 22u_0402 | MLCC 22uF/6.3V 0402 - VDDCR_SOC-Bank unter Sockel | Murata GRM155R60J226ME15 | R_0603
C33 | 22u_0402 | MLCC 22uF/6.3V 0402 - VDDCR_SOC-Bank unter Sockel | Murata GRM155R60J226ME15 | R_0603
C34 | 22u_0402 | MLCC 22uF/6.3V 0402 - VDDCR_SOC-Bank unter Sockel | Murata GRM155R60J226ME15 | R_0603
C35 | 22u_0402 | MLCC 22uF/6.3V 0402 - VDDCR_SOC-Bank unter Sockel | Murata GRM155R60J226ME15 | R_0603
C36 | 22u_0402 | MLCC 22uF/6.3V 0402 - VDDCR_SOC-Bank unter Sockel | Murata GRM155R60J226ME15 | R_0603
C37 | 22u_0402 | MLCC 22uF/6.3V 0402 - VDDCR_SOC-Bank unter Sockel | Murata GRM155R60J226ME15 | R_0603
C40 | 10u_0603 | MLCC 10uF/10V 0603 - Schiene +1V1_MEM | Murata GRM188R61A106KE69 | R_0603
C41 | 10u_0603 | MLCC 10uF/10V 0603 - Schiene +1V1_MEM | Murata GRM188R61A106KE69 | R_0603
C42 | 10u_0603 | MLCC 10uF/10V 0603 - Schiene +1V8 | Murata GRM188R61A106KE69 | R_0603
C43 | 10u_0603 | MLCC 10uF/10V 0603 - Schiene +3V3 | Murata GRM188R61A106KE69 | R_0603
C44 | 10u_0603 | MLCC 10uF/10V 0603 - Schiene +3V3 | Murata GRM188R61A106KE69 | R_0603
C45 | 10u_0603 | MLCC 10uF/10V 0603 - Schiene +5V | Murata GRM188R61A106KE69 | R_0603
C46 | 10u_0603 | MLCC 10uF/10V 0603 - Schiene +5V | Murata GRM188R61A106KE69 | R_0603
C47 | 10u_0603 | MLCC 10uF/10V 0603 - Schiene +1V05_TB | Murata GRM188R61A106KE69 | R_0603
C48 | 10u_0603 | MLCC 10uF/10V 0603 - Schiene +0V88_TB | Murata GRM188R61A106KE69 | R_0603
C49 | 10u_0603 | MLCC 10uF/10V 0603 - Schiene +3V3_ALW | Murata GRM188R61A106KE69 | R_0603
C52 | 100n_0402 | MLCC 100nF 0402 x4 - Entkopplung U1 PD | Murata GRM155R71C104KA88 | R_0603
C53 | 100n_0402 | MLCC 100nF 0402 x4 - Entkopplung U3 Lader | Murata GRM155R71C104KA88 | R_0603
C54 | 100n_0402 | MLCC 100nF 0402 x4 - Entkopplung U11 VRM | Murata GRM155R71C104KA88 | R_0603
C55 | 100n_0402 | MLCC 100nF 0402 x4 - Entkopplung U19 BIOS | Murata GRM155R71C104KA88 | R_0603
C56 | 100n_0402 | MLCC 100nF 0402 x4 - Entkopplung U23 TB4 | Murata GRM155R71C104KA88 | R_0603
C57 | 100n_0402 | MLCC 100nF 0402 x4 - Entkopplung U34 LAN | Murata GRM155R71C104KA88 | R_0603
C58 | 100n_0402 | MLCC 100nF 0402 x4 - Entkopplung U39 Codec | Murata GRM155R71C104KA88 | R_0603
C59 | 100n_0402 | MLCC 100nF 0402 x4 - Entkopplung U41 EC | Murata GRM155R71C104KA88 | R_0603
C60 | 100n_0402 | MLCC 100nF 0402 x4 - Entkopplung U42 ECFlash | Murata GRM155R71C104KA88 | R_0603
C61 | 100n_0402 | MLCC 100nF 0402 x4 - Entkopplung Sockel-Rand | Murata GRM155R71C104KA88 | R_0603
U50 | TPD4E02B04 | ESD-Array 4-Kanal 0.25pF - TB0 Lane1 | TI TPD4E02B04DQAR | DFN6_2x2
U51 | TPD4E02B04 | ESD-Array 4-Kanal 0.25pF - TB0 Lane2 | TI TPD4E02B04DQAR | DFN6_2x2
U52 | TPD4E02B04 | ESD-Array 4-Kanal 0.25pF - TB1 Lane1 | TI TPD4E02B04DQAR | DFN6_2x2
U53 | TPD4E02B04 | ESD-Array 4-Kanal 0.25pF - TB1 Lane2 | TI TPD4E02B04DQAR | DFN6_2x2
U54 | TPD4E02B04 | ESD-Array 4-Kanal 0.25pF - USB-A1 SS | TI TPD4E02B04DQAR | DFN6_2x2
U55 | TPD4E02B04 | ESD-Array 4-Kanal 0.25pF - USB-A2 SS | TI TPD4E02B04DQAR | DFN6_2x2
U56 | TPD4E02B04 | ESD-Array 4-Kanal 0.25pF - HDMI D0/D1 | TI TPD4E02B04DQAR | DFN6_2x2
U57 | TPD4E02B04 | ESD-Array 4-Kanal 0.25pF - HDMI D2/CLK | TI TPD4E02B04DQAR | DFN6_2x2
U58 | TPD4E02B04 | ESD-Array 4-Kanal 0.25pF - USB-C CC-Pins | TI TPD4E02B04DQAR | DFN6_2x2
U59 | TPD4E02B04 | ESD-Array 4-Kanal 0.25pF - TB USB2 | TI TPD4E02B04DQAR | DFN6_2x2
U60 | TPD4E02B04 | ESD-Array 4-Kanal 0.25pF - USB-A USB2 | TI TPD4E02B04DQAR | DFN6_2x2
FL1 | DLW21SN900 | USB2-Gleichtaktdrossel 90 Ohm - Webcam | Murata DLW21SN900SQ2L | R_0603
FL2 | DLW21SN900 | USB2-Gleichtaktdrossel 90 Ohm - WLAN/BT | Murata DLW21SN900SQ2L | R_0603
R10 | R_10k | Pulldown TB Force-Power | Yageo RC0402FR-0710KL | R_0603
R11 | R_10k | Pullup PCIe-Wake (Open-Drain) | Yageo RC0402FR-0710KL | R_0603
R12 | R_10k | Pullup PROCHOT# (Open-Drain) | Yageo RC0402FR-0710KL | R_0603
R13 | R_10k | Pullup DDR5-SPD-Bus | Yageo RC0402FR-0710KL | R_0603
R14 | R_10k | Pullup DDR5-SPD-Bus | Yageo RC0402FR-0710KL | R_0603
R15 | R_10k | Pullup Power-Taste | Yageo RC0402FR-0710KL | R_0603

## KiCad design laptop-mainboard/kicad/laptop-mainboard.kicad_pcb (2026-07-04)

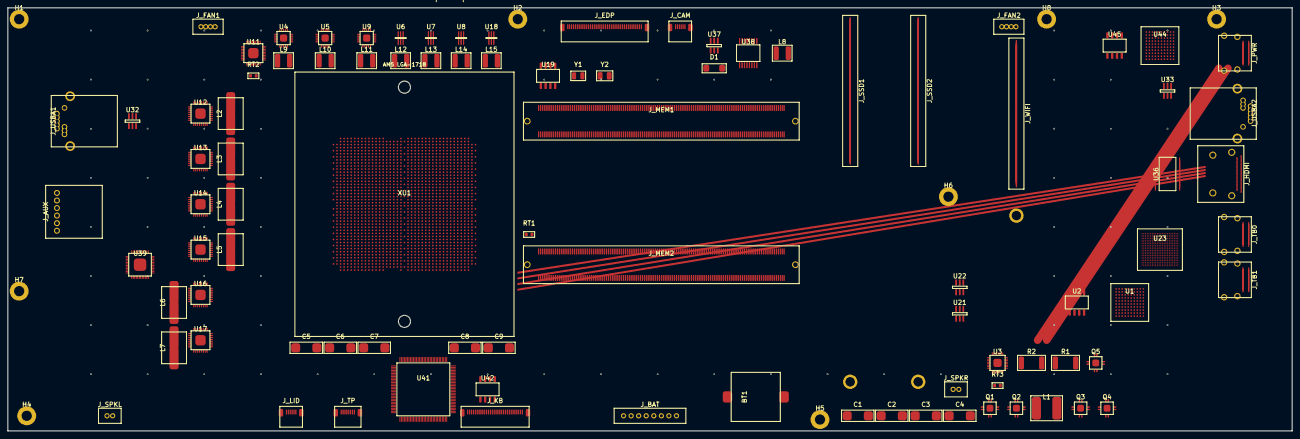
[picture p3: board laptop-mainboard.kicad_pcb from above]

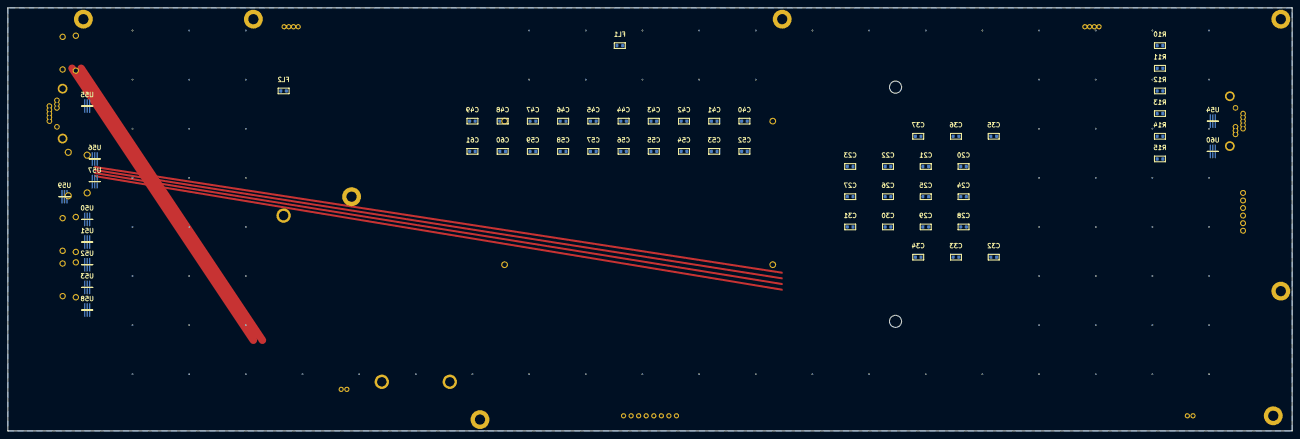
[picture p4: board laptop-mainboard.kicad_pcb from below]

Board: 8 copper layers, 340.0 x 112.0 mm, 157 parts (57 on the bottom side), 7 nets.

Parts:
BT1: ML1220; COIN_ML1220
C1, C2, C3, C4: 330u; CAP_7343
C5, C6, C7, C8, C9: 470u; CAP_7343
C20, C21, C22, C23, C24, C25, C26, C27, C28, C29, C30, C31, C32, C33, C34, C35, C36, C37: 22u; R_0603
C40, C41, C42, C43, C44, C45, C46, C47, C48, C49: 10u; R_0603
C52, C53, C54, C55, C56, C57, C58, C59, C60, C61: 100n; R_0603
D1: SS3P4; SMA_DIODE
FL1: CMC Webcam; R_0603
FL2: CMC WLAN; R_0603
H1, H2, H3, H4, H5, H6, H7, H8: MTG_M2_5
J_AUX: Klinke; TRRS_35
J_BAT: HP-Akku 3S 56Wh; CONN_BAT8_2mm
J_CAM: Webcam; FPC6_05
J_EDP: eDP-Panel; FPC40_05
J_FAN1: Luefter L; CONN_FAN4
J_FAN2: Luefter R; CONN_FAN4
J_HDMI: HDMI 2.1; HDMI_A
J_KB: HP-Tastatur; FPC30_05
J_LID: Lid-Sensor; FPC6_05
J_MEM1: DDR5 SO-DIMM A; SODIMM_DDR5_262
J_MEM2: DDR5 SO-DIMM B; SODIMM_DDR5_262
J_PWR: USB-C Ladeport 100W; USBC_24
J_SPKL: Spk L; CONN_SPK2
J_SPKR: Spk R; CONN_SPK2
J_SSD1, J_SSD2: NVMe Gen4 x4; M2_M_2280
J_TB0, J_TB1: USB-C TB4; USBC_24
J_TP: HP-Clickpad; FPC8_05
J_USBA1, J_USBA2: USB-A 5G; USBA3_TH
J_WIFI: WLAN/BT; M2_E_2230
L1: 3u3; IND_7x7
L2, L3, L4, L5, L6, L7: 220n; IND_7x7
L8: 10u; IND_4x4
L9, L10, L11: 1u; IND_4x4
L12, L13, L14, L15: 470n; IND_4x4
Q1, Q2, Q3, Q4: SiSS22DN; PowerPAK_1212
Q5: BATFET; PowerPAK_1212
R1, R2: 10m; R_2512
R10, R11, R12, R13, R14, R15: 10k; R_0603
RT1: NTC CPU; R_0603
RT2: NTC VRM; R_0603
RT3: NTC CHG; R_0603
U1: TPS65988 PD; BGA96_9x9
U2: PD-Cfg; SOIC8
U3: BQ25731; QFN32_4x4
U4: 5V Buck; QFN20_3x4
U5: 3V3 Buck; QFN20_3x4
U6: 1V8; DFN6_2x2
U7: 1V05_TB; DFN6_2x2
U8: 0V88_TB; DFN6_2x2
U9: 3V3_ALW; QFN20_3x4
U11: MP2857; QFN40_5x5
U12: Stage CPU1; QFN31_5x5
U13: Stage CPU2; QFN31_5x5
U14: Stage CPU3; QFN31_5x5
U15: Stage CPU4; QFN31_5x5
U16: Stage SOC1; QFN31_5x5
U17: Stage SOC2; QFN31_5x5
U18: 1V1_MEM; DFN6_2x2
U19: W25Q256JW; SOIC8
U21: SSD1-SW; SOT23-5
U22: SSD2-SW; SOT23-5
U23: JHL8540 TB4; BGA_10x9_JHL8540
U32, U33: VBUS-SW; SOT23-5
U36: TPD12S016; TSSOP24
U37: VLCD-SW; SOT23-5
U38: MP3389 BL; TSSOP16EP
U39: ALC256; QFN48_6x6
U41: IT5570E EC; LQFP128_14x14
U42: EC-Flash; SOIC8
U44: TPS65987D Ladeport; BGA96_9x9
U45: PD2-Cfg; SOIC8
U50: ESD TB0-L1; DFN6_2x2
U51: ESD TB0-L2; DFN6_2x2
U52: ESD TB1-L1; DFN6_2x2
U53: ESD TB1-L2; DFN6_2x2
U54: ESD USBA1; DFN6_2x2
U55: ESD USBA2; DFN6_2x2
U56: ESD HDMI-1; DFN6_2x2
U57: ESD HDMI-2; DFN6_2x2
U58: ESD CC; DFN6_2x2
U59: ESD TB-USB2; DFN6_2x2
U60: ESD A-USB2; DFN6_2x2
XU1: Ryzen 5 8600G; AM5_Socket_LGA1718
Y1: 32.768k; XTAL_3215
Y2: 48M; XTAL_3225

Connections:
+1V1_MEM: XU1.L19, XU1.L20, XU1.L23, XU1.L24, XU1.L25, XU1.L26, XU1.L27, XU1.L28, XU1.L29, XU1.L30, XU1.M20, XU1.M24, XU1.M26, XU1.M28, XU1.M29, XU1.N19, XU1.N23, XU1.N25, XU1.N27, XU1.P22, XU1.P24, XU1.P26, XU1.P28
+1V8: XU1.AN9, XU1.AN11, XU1.AP7, XU1.AP8, XU1.AP10, XU1.AP11, XU1.AP13, XU1.AP15, XU1.AP18, XU1.AP19, XU1.AP20, XU1.AR8, XU1.AR12, XU1.AR14, XU1.AR19, XU1.AT7, XU1.AT8, XU1.AT9, XU1.AT10, XU1.AT11, XU1.AT12, XU1.AT13, XU1.AT14, XU1.AT15, XU1.AT18, XU1.AT19
+VDDCR_CPU: XU1.AA7, XU1.AA8, XU1.AA10, XU1.AA12, XU1.AA14, XU1.AA16, XU1.AA18, XU1.AA20, XU1.AA22, XU1.AA24, XU1.AA26, XU1.AA28, XU1.AA29, XU1.AB7, XU1.AB8, XU1.AB13, XU1.AB15, XU1.AB17, XU1.AB19, XU1.AB21, XU1.AB23, XU1.AB25, XU1.AB27, XU1.AC7, XU1.AC8, XU1.AC10, XU1.AC12, XU1.AC14, XU1.AC18, XU1.AC20, XU1.AC22, XU1.AC24, XU1.AC26, XU1.AC28, XU1.AD7, XU1.AD8, XU1.AD11, XU1.AD15, XU1.AD17, XU1.AD19, XU1.AD23, XU1.AD25, XU1.AD27, XU1.AD29, XU1.AE8, XU1.AE10, XU1.AE16, XU1.AE18, XU1.AE20, XU1.AE22, XU1.AE24, XU1.AE26, XU1.AE28, XU1.AE29, XU1.AF7, XU1.AF8, XU1.AF11, XU1.AF13, XU1.AF15, XU1.AF17, XU1.AF19, XU1.AF23, XU1.AF25, XU1.AF27, XU1.AF30, XU1.AG7, XU1.AG8, XU1.AG12, XU1.AG14, XU1.AG16, XU1.AG18, XU1.AG20, XU1.AG22, XU1.AG24, XU1.AG26, XU1.AG28, XU1.AG29, XU1.AH7, XU1.AH8, XU1.AH10, XU1.AH15, XU1.AH17, XU1.AH19, XU1.AH23, XU1.AH25, XU1.AH27, XU1.AH29, XU1.AJ8, XU1.AJ11, XU1.AJ18, XU1.AJ20, XU1.AJ22, XU1.AJ24, XU1.AJ26, XU1.AJ28, XU1.AK7, XU1.AK8, XU1.AK13, XU1.AK15, XU1.AK17, XU1.AK19, XU1.AK23, XU1.AK25, XU1.AK27, XU1.AL7, XU1.AL8, XU1.AL12, XU1.AL14, XU1.AL18, XU1.AL20, XU1.AL22, XU1.AL24, XU1.AL26, XU1.AL28, XU1.AM7, XU1.AM8, XU1.AM10, XU1.AM12, XU1.AM15, XU1.AM17, XU1.AM19, XU1.AM23, XU1.AM25, XU1.AM27, XU1.AN22, XU1.AN24, XU1.AN26, XU1.AN28, XU1.R7, XU1.R8, XU1.R9, XU1.R11, XU1.R13, XU1.R14, XU1.R15, XU1.R16, XU1.R17, XU1.R18, XU1.R19, XU1.R20, XU1.R22, XU1.R23, XU1.R24, XU1.R25, XU1.R26, XU1.R27, XU1.R28, XU1.T8, XU1.T10, XU1.T15, XU1.T17, XU1.T19, XU1.T21, XU1.T23, XU1.T25, XU1.T27, XU1.T28, XU1.U7, XU1.U8, XU1.U11, XU1.U14, XU1.U16, XU1.U18, XU1.U20, XU1.U22, XU1.U24, XU1.U26, XU1.U28, XU1.U29, XU1.V7, XU1.V8, XU1.V13, XU1.V15, XU1.V17, XU1.V19, XU1.V21, XU1.V23, XU1.V25, XU1.V27, XU1.V29, XU1.W7, XU1.W8, XU1.W11, XU1.W14, XU1.W16, XU1.W18, XU1.W20, XU1.W22, XU1.W24, XU1.W26, XU1.W28, XU1.W30, XU1.Y8, XU1.Y10, XU1.Y13, XU1.Y15, XU1.Y17, XU1.Y19, XU1.Y21, XU1.Y23, XU1.Y25, XU1.Y27, XU1.Y29
+VDDCR_SOC: XU1.L8, XU1.L9, XU1.L10, XU1.L11, XU1.L12, XU1.L13, XU1.L14, XU1.L15, XU1.L16, XU1.L17, XU1.L18, XU1.M8, XU1.M10, XU1.M12, XU1.M14, XU1.M16, XU1.M18, XU1.N11, XU1.N15, XU1.N17, XU1.P10, XU1.P12, XU1.P14, XU1.P16
GND: XU1.A4, XU1.A8, XU1.A9, XU1.A11, XU1.A13, XU1.A15, XU1.A20, XU1.A23, XU1.A25, XU1.A28, XU1.A31, XU1.A34, XU1.A37, XU1.AA1, XU1.AA4, XU1.AA5, XU1.AA11, XU1.AA15, XU1.AA17, XU1.AA19, XU1.AA23, XU1.AA25, XU1.AA27, XU1.AA30, XU1.AA32, XU1.AA35, XU1.AA37, XU1.AA38, XU1.AA41, XU1.AB2, XU1.AB3, XU1.AB4, XU1.AB5, XU1.AB6, XU1.AB10, XU1.AB14, XU1.AB16, XU1.AB18, XU1.AB20, XU1.AB22, XU1.AB24, XU1.AB26, XU1.AB28, XU1.AB29, XU1.AB31, XU1.AB33, XU1.AB36, XU1.AB39, XU1.AC3, XU1.AC6, XU1.AC9, XU1.AC11, XU1.AC13, XU1.AC17, XU1.AC19, XU1.AC21, XU1.AC23, XU1.AC25, XU1.AC27, XU1.AC29, XU1.AC31, XU1.AC33, XU1.AC36, XU1.AC39, XU1.AD1, XU1.AD3, XU1.AD4, XU1.AD5, XU1.AD12, XU1.AD14, XU1.AD16, XU1.AD18, XU1.AD20, XU1.AD22, XU1.AD24, XU1.AD26, XU1.AD28, XU1.AD30, XU1.AD32, XU1.AD35, XU1.AD37, XU1.AD38, XU1.AD41, XU1.AE2, XU1.AE3, XU1.AE4, XU1.AE6, XU1.AE9, XU1.AE11, XU1.AE13, XU1.AE15, XU1.AE17, XU1.AE19, XU1.AE21, XU1.AE23, XU1.AE25, XU1.AE27, XU1.AE30, XU1.AE32, XU1.AE33, XU1.AE36, XU1.AE39, XU1.AF1, XU1.AF2, XU1.AF4, XU1.AF6, XU1.AF9, XU1.AF14, XU1.AF16, XU1.AF18, XU1.AF20, XU1.AF22, XU1.AF24, XU1.AF26, XU1.AF28, XU1.AF29, XU1.AF31, XU1.AF33, XU1.AF35, XU1.AF37, XU1.AF38, XU1.AF41, XU1.AG3, XU1.AG5, XU1.AG6, XU1.AG10, XU1.AG13, XU1.AG15, XU1.AG17, XU1.AG19, XU1.AG21, XU1.AG23, XU1.AG25, XU1.AG27, XU1.AG30, XU1.AG32, XU1.AG33, XU1.AG36, XU1.AG39, XU1.AH1, XU1.AH3, XU1.AH4, XU1.AH5, XU1.AH11, XU1.AH12, XU1.AH14, XU1.AH16, XU1.AH18, XU1.AH20, XU1.AH22, XU1.AH24, XU1.AH26, XU1.AH28, XU1.AH30, XU1.AH31, XU1.AH33, XU1.AH35, XU1.AH37, XU1.AH38, XU1.AH41, XU1.AJ2, XU1.AJ3, XU1.AJ4, XU1.AJ6, XU1.AJ9, XU1.AJ10, XU1.AJ13, XU1.AJ15, XU1.AJ19, XU1.AJ21, XU1.AJ23, XU1.AJ25, XU1.AJ27, XU1.AJ29, XU1.AJ31, XU1.AJ32, XU1.AJ33, XU1.AJ36, XU1.AJ39, XU1.AK1, XU1.AK2, XU1.AK4, XU1.AK6, XU1.AK9, XU1.AK11, XU1.AK14, XU1.AK16, XU1.AK18, XU1.AK20, XU1.AK22, XU1.AK24, XU1.AK26, XU1.AK28, XU1.AK30, XU1.AK33, XU1.AK35, XU1.AK37, XU1.AK38, XU1.AK41, XU1.AL3, XU1.AL5, XU1.AL6, XU1.AL10, XU1.AL13, XU1.AL15, XU1.AL19, XU1.AL21, XU1.AL23, XU1.AL25, XU1.AL27, XU1.AL30, XU1.AL32, XU1.AL33, XU1.AL36, XU1.AL39, XU1.AM1, XU1.AM3, XU1.AM4, XU1.AM5, XU1.AM11, XU1.AM14, XU1.AM16, XU1.AM18, XU1.AM20, XU1.AM22, XU1.AM24, XU1.AM26, XU1.AM28, XU1.AM31, XU1.AM33, XU1.AM35, XU1.AM37, XU1.AM38, XU1.AM41, XU1.AN2, XU1.AN3, XU1.AN4, XU1.AN6, XU1.AN8, XU1.AN10, XU1.AN13, XU1.AN15, XU1.AN18, XU1.AN19, XU1.AN20, XU1.AN21, XU1.AN23, XU1.AN25, XU1.AN27, XU1.AN29, XU1.AN30, XU1.AN32, XU1.AN33, XU1.AN36, XU1.AN38, XU1.AN39, XU1.AP1, XU1.AP2, XU1.AP4, XU1.AP6, XU1.AP14, XU1.AP16, XU1.AP23, XU1.AP32, XU1.AP35, XU1.AP37, XU1.AP38, XU1.AP40, XU1.AP41, XU1.AR3, XU1.AR5, XU1.AR6, XU1.AR9, XU1.AR11, XU1.AR13, XU1.AR15, XU1.AR18, XU1.AR21, XU1.AR24, XU1.AR27, XU1.AR28, XU1.AR30, XU1.AR31, XU1.AR33, XU1.AR34, XU1.AR35, XU1.AR36, XU1.AR39, XU1.AT1, XU1.AT3, XU1.AT4, XU1.AT5, XU1.AT24, XU1.AT26, XU1.AT29, XU1.AT32, XU1.AT35, XU1.AT37, XU1.AT38, XU1.AT41, XU1.AU2, XU1.AU3, XU1.AU6, XU1.AU7, XU1.AU9, XU1.AU12, XU1.AU15, XU1.AU18, XU1.AU21, XU1.AU23, XU1.AU24, XU1.AU27, XU1.AU30, XU1.AU33, XU1.AU36, XU1.AU39, XU1.AV2, XU1.AV4, XU1.AV7, XU1.AV10, XU1.AV13, XU1.AV16, XU1.AV19, XU1.AV23, XU1.AV26, XU1.AV29, XU1.AV31, XU1.AV32, XU1.AV35, XU1.AV37, XU1.AV38, XU1.AV41, XU1.AW3, XU1.AW6, XU1.AW9, XU1.AW12, XU1.AW15, XU1.AW18, XU1.AW21, XU1.AW22, XU1.AW25, XU1.AW27, XU1.AW30, XU1.AW33, XU1.AW36, XU1.AW38, XU1.AW39, XU1.AW40, XU1.AY4, XU1.AY7, XU1.AY10, XU1.AY13, XU1.AY16, XU1.AY19, XU1.AY23, XU1.AY24, XU1.AY25, XU1.AY26, XU1.AY27, XU1.AY28, XU1.AY29, XU1.AY30, XU1.AY31, XU1.AY32, XU1.AY33, XU1.AY34, XU1.AY35, XU1.AY36, XU1.AY37, XU1.AY38, XU1.AY41, XU1.B6, XU1.B8, XU1.B9, XU1.B11, XU1.B13, XU1.B15, XU1.B18, XU1.B21, XU1.B23, XU1.B26, XU1.B29, XU1.B30, XU1.B32, XU1.B35, XU1.B37, XU1.B39, XU1.BA3, XU1.BA6, XU1.BA9, XU1.BA12, XU1.BA15, XU1.BA18, XU1.BA21, XU1.BA23, XU1.BA25, XU1.BA26, XU1.BA29, XU1.BA32, XU1.BA33, XU1.BA36, XU1.BA39, XU1.BB4, XU1.BB7, XU1.BB10, XU1.BB13, XU1.BB16, XU1.BB19, XU1.BB23, XU1.BB25, XU1.BB28, XU1.BB31, XU1.BB34, XU1.BB37, XU1.BB38, XU1.BB41, XU1.BC3, XU1.BC6, XU1.BC9, XU1.BC12, XU1.BC15, XU1.BC18, XU1.BC21, XU1.BC23, XU1.BC26, XU1.BC29, XU1.BC30, XU1.BC32, XU1.BC35, XU1.BC37, XU1.BC39, XU1.BD4, XU1.BD7, XU1.BD10, XU1.BD13, XU1.BD23, XU1.BD25, XU1.BD28, XU1.BD31, XU1.BD34, XU1.BD37, XU1.C1, XU1.C4, XU1.C7, XU1.C8, XU1.C9, XU1.C10, XU1.C11, XU1.C12, XU1.C13, XU1.C14, XU1.C15, XU1.C16, XU1.C17, XU1.C18, XU1.C19, XU1.C20, XU1.C22, XU1.C23, XU1.C25, XU1.C28, XU1.C31, XU1.C34, XU1.C37, XU1.C38, XU1.C41, XU1.D3, XU1.D6, XU1.D11, XU1.D15, XU1.D22, XU1.D23, XU1.D25, XU1.D26, XU1.D29, XU1.D32, XU1.D33, XU1.D36, XU1.D39, XU1.E1, XU1.E4, XU1.E6, XU1.E7, XU1.E8, XU1.E9, XU1.E10, XU1.E11, XU1.E12, XU1.E13, XU1.E14, XU1.E15, XU1.E16, XU1.E17, XU1.E18, XU1.E19, XU1.E20, XU1.E22, XU1.E23, XU1.E24, XU1.E25, XU1.E26, XU1.E27, XU1.E28, XU1.E29, XU1.E30, XU1.E31, XU1.E32, XU1.E33, XU1.E34, XU1.E35, XU1.E36, XU1.E37, XU1.E38, XU1.E41, XU1.F3, XU1.F6, XU1.F7, XU1.F10, XU1.F13, XU1.F16, XU1.F19, XU1.F22, XU1.F25, XU1.F27, XU1.F30, XU1.F33, XU1.F36, XU1.F38, XU1.F39, XU1.F40, XU1.G1, XU1.G4, XU1.G5, XU1.G6, XU1.G7, XU1.G8, XU1.G9, XU1.G10, XU1.G11, XU1.G12, XU1.G13, XU1.G14, XU1.G15, XU1.G16, XU1.G17, XU1.G18, XU1.G19, XU1.G20, XU1.G22, XU1.G23, XU1.G26, XU1.G29, XU1.G31, XU1.G32, XU1.G35, XU1.G37, XU1.G38, XU1.G41, XU1.H2, XU1.H3, XU1.H5, XU1.H8, XU1.H11, XU1.H14, XU1.H17, XU1.H20, XU1.H23, XU1.H24, XU1.H27, XU1.H30, XU1.H33, XU1.H36, XU1.H39, XU1.J1, XU1.J3, XU1.J4, XU1.J5, XU1.J6, XU1.J7, XU1.J8, XU1.J9, XU1.J10, XU1.J11, XU1.J12, XU1.J13, XU1.J14, XU1.J15, XU1.J16, XU1.J17, XU1.J18, XU1.J19, XU1.J20, XU1.J22, XU1.J23, XU1.J24, XU1.J26, XU1.J29, XU1.J32, XU1.J35, XU1.J37, XU1.J38, XU1.J41, XU1.K3, XU1.K5, XU1.K6, XU1.K9, XU1.K12, XU1.K15, XU1.K18, XU1.K21, XU1.K24, XU1.K25, XU1.K26, XU1.K27, XU1.K28, XU1.K30, XU1.K31, XU1.K32, XU1.K33, XU1.K34, XU1.K35, XU1.K36, XU1.K39, XU1.L1, XU1.L2, XU1.L4, XU1.L6, XU1.L7, XU1.L31, XU1.L32, XU1.L35, XU1.L37, XU1.L38, XU1.L40, XU1.L41, XU1.M2, XU1.M3, XU1.M4, XU1.M6, XU1.M9, XU1.M11, XU1.M13, XU1.M15, XU1.M17, XU1.M19, XU1.M23, XU1.M25, XU1.M27, XU1.M30, XU1.M32, XU1.M33, XU1.M36, XU1.M38, XU1.M39, XU1.N1, XU1.N3, XU1.N4, XU1.N5, XU1.N7, XU1.N8, XU1.N10, XU1.N12, XU1.N16, XU1.N18, XU1.N20, XU1.N24, XU1.N26, XU1.N28, XU1.N31, XU1.N33, XU1.N35, XU1.N37, XU1.N38, XU1.N41, XU1.P3, XU1.P5, XU1.P6, XU1.P7, XU1.P8, XU1.P13, XU1.P15, XU1.P17, XU1.P21, XU1.P23, XU1.P25, XU1.P27, XU1.P30, XU1.P32, XU1.P33, XU1.P36, XU1.P39, XU1.R1, XU1.R2, XU1.R4, XU1.R6, XU1.R30, XU1.R33, XU1.R35, XU1.R37, XU1.R38, XU1.R41, XU1.T2, XU1.T3, XU1.T4, XU1.T6, XU1.T9, XU1.T11, XU1.T13, XU1.T16, XU1.T18, XU1.T20, XU1.T22, XU1.T24, XU1.T26, XU1.T29, XU1.T31, XU1.T32, XU1.T33, XU1.T36, XU1.T39, XU1.U1, XU1.U3, XU1.U4, XU1.U5, XU1.U10, XU1.U12, XU1.U15, XU1.U17, XU1.U19, XU1.U23, XU1.U25, XU1.U27, XU1.U30, XU1.U31, XU1.U33, XU1.U35, XU1.U37, XU1.U38, XU1.U41, XU1.V3, XU1.V5, XU1.V6, XU1.V10, XU1.V12, XU1.V14, XU1.V16, XU1.V18, XU1.V20, XU1.V22, XU1.V24, XU1.V26, XU1.V28, XU1.V30, XU1.V32, XU1.V33, XU1.V36, XU1.V39, XU1.W1, XU1.W2, XU1.W4, XU1.W6, XU1.W9, XU1.W13, XU1.W15, XU1.W17, XU1.W19, XU1.W23, XU1.W25, XU1.W27, XU1.W29, XU1.W31, XU1.W33, XU1.W35, XU1.W37, XU1.W38, XU1.W41, XU1.Y2, XU1.Y3, XU1.Y4, XU1.Y6, XU1.Y9, XU1.Y11, XU1.Y16, XU1.Y18, XU1.Y20, XU1.Y22, XU1.Y24, XU1.Y26, XU1.Y28, XU1.Y30, XU1.Y32, XU1.Y33, XU1.Y36, XU1.Y39
VDD_18_S5: XU1.AR20, XU1.AT20
VDD_MISC_S5: XU1.AP17, XU1.AT16, XU1.AT17

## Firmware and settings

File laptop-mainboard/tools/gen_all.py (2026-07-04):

#!/usr/bin/env python3
"""Erzeugt das komplette KiCad-Projekt des Laptop-Mainboards.

Aufruf:  python3 tools/gen_all.py   (aus laptop-mainboard/)
Ausgabe: kicad/  (Projekt, Schaltplaene, Board, Footprint-Lib) + docs/bom.csv
"""
import json
import os
import sys

sys.path.insert(0, os.path.dirname(os.path.abspath(__file__)))

from kicadgen.sexpr import uid, check_balanced, reset_uids
from kicadgen import sch
from kicadgen.sch import sheet_file, root_file, place, note, symbol_lib
from kicadgen import boarddata as d1
from kicadgen import boarddata2 as d2
from kicadgen import pcb

BASE = os.path.dirname(os.path.dirname(os.path.abspath(__file__)))
KICAD = os.path.join(BASE, "kicad")
DOCS = os.path.join(BASE, "docs")


def write(path, text, name=None):
    check_balanced(text, name or os.path.basename(path))
    with open(path, "w") as fh:
        fh.write(text)
    print(f"  {os.path.relpath(path, BASE)}  ({len(text)//1024} KB)")


def main():
    reset_uids()
    os.makedirs(KICAD, exist_ok=True)
    os.makedirs(os.path.join(KICAD, "laptop_mainboard.pretty"), exist_ok=True)
    os.makedirs(DOCS, exist_ok=True)

    sheets_src = [
        d1.sheet_power(), d1.sheet_vrm(), d1.sheet_cpu(), d1.sheet_memory(),
        d1.sheet_storage(), d2.sheet_usb_tb(), d2.sheet_ladeport(),
        d2.sheet_display(), d2.sheet_audio_sd_ec(), d2.sheet_kleinteile(),
    ]

    root_uuid = uid("root")
    all_comps = []
    sheet_meta = []
    for page, (title, fname, comps_xy, notes) in enumerate(sheets_src, start=2):
        s_uuid = uid("sheet" + fname)
        file_uuid = uid("file" + fname)
        placed, libs = [], []
        for comp, x, y in comps_xy:
            libs.append(comp)
            placed.append(place(comp, x, y, root_uuid, s_uuid))
            all_comps.append(comp)
        note_blocks = [note(t, 20, 260 + i * 5) for i, t in enumerate(notes)]
        text = sheet_file(file_uuid, title, placed, libs, note_blocks)
        write(os.path.join(KICAD, fname), text)
        sheet_meta.append((title, fname, s_uuid, page))

    # Root-Blatt
    sheets_layout = []
    for i, (title, fname, s_uuid, page) in enumerate(sheet_meta):
        x = 30 + (i % 3) * 130
        y = 40 + (i // 3) * 60
        sheets_layout.append((title, fname, s_uuid, x, y, str(page)))
    root_notes = [
        note("Laptop-Mainboard fuer HP-EliteBook-850-G7-Chassis - Ryzen 5 8600G (AM5, gesockelt)", 30, 240, 3),
        note("2x DDR5 SO-DIMM | 2x M.2 NVMe Gen4 | WLAN | AM5-Pinbelegung: docs/am5_pinmap.csv", 30, 250, 2),
        note("Ports wie 850 G7: USB-C-Ladeport 100W (Barrel-Position), 2x USB-C TB4, HDMI, 2x USB-A, Klinke", 30, 257, 2),
        note("Generiert aus tools/gen_all.py - Aenderungen dort vornehmen.", 30, 267, 1.6),
    ]
    write(os.path.join(KICAD, "laptop-mainboard.kicad_sch"),
          root_file(root_uuid, sheets_layout, "Laptop-Mainboard - Uebersicht",
                    root_notes))

    # Symbolbibliothek
    write(os.path.join(KICAD, "lm.kicad_sym"), symbol_lib(all_comps))

    # Projektdatei + Lib-Tabellen
    pro = {
        "board": {"3dviewports": [], "design_settings": {}, "layer_presets": [],
                   "viewports": []},
        "libraries": {"pinned_footprint_libs": ["laptop_mainboard"],
                       "pinned_symbol_libs": ["lm"]},
        "meta": {"filename": "laptop-mainboard.kicad_pro", "version": 1},
        "sheets": [[root_uuid, "Root"]],
        "text_variables": {},
    }
    with open(os.path.join(KICAD, "laptop-mainboard.kicad_pro"), "w") as fh:
        json.dump(pro, fh, indent=2)
    print("  kicad/laptop-mainboard.kicad_pro")
    with open(os.path.join(KICAD, "sym-lib-table"), "w") as fh:
        fh.write('(sym_lib_table\n  (version 7)\n'
                 '  (lib (name "lm")(type "KiCad")(uri "${KIPRJMOD}/lm.kicad_sym")'
                 '(options "")(descr "Projekt-Symbole"))\n)\n')
    with open(os.path.join(KICAD, "fp-lib-table"), "w") as fh:
        fh.write('(fp_lib_table\n  (version 7)\n'
                 '  (lib (name "laptop_mainboard")(type "KiCad")'
                 '(uri "${KIPRJMOD}/laptop_mainboard.pretty")'
                 '(options "")(descr "Projekt-Footprints"))\n)\n')

    # Footprint-Bibliothek
    lib = pcb.build_library()
    for name, fp in lib.items():
        write(os.path.join(KICAD, "laptop_mainboard.pretty", name + ".kicad_mod"),
              fp.mod_file())

    # ------------------------------------------------------------------
    # Board: 340 x 112 mm fuer HP-EliteBook-850-G7-Chassis (358.5 x 233.9mm)
    # Rechte Kante (hinten->vorn, nach Foto): USB-C-Ladeport (Barrel-
    # Position), USB-A, HDMI, 2x USB-C TB4. Links: USB-A, Klinke.
    # ------------------------------------------------------------------
    PL = [
        # CPU + Speicher + Storage
        ("AM5_Socket_LGA1718", "XU1", "Ryzen 5 8600G", 130, 82, 0),
        ("SODIMM_DDR5_262", "J_MEM1", "DDR5 SO-DIMM A", 198, 60, 0),
        ("SODIMM_DDR5_262", "J_MEM2", "DDR5 SO-DIMM B", 198, 98, 0),
        ("M2_M_2280", "J_SSD1", "NVMe Gen4 x4", 248, 52, 270),
        ("M2_M_2280", "J_SSD2", "NVMe Gen4 x4", 266, 52, 270),
        ("M2_E_2230", "J_WIFI", "WLAN/BT", 292, 58, 270),
        # VRM links vom Sockel
        ("QFN40_5x5", "U11", "MP2857", 90, 42, 0),
        ("QFN31_5x5", "U12", "Stage CPU1", 76, 58, 0),
        ("QFN31_5x5", "U13", "Stage CPU2", 76, 70, 0),
        ("QFN31_5x5", "U14", "Stage CPU3", 76, 82, 0),
        ("QFN31_5x5", "U15", "Stage CPU4", 76, 94, 0),
        ("QFN31_5x5", "U16", "Stage SOC1", 76, 106, 0),
        ("QFN31_5x5", "U17", "Stage SOC2", 76, 118, 0),
        ("IND_7x7", "L2", "220n", 84, 58, 90),
        ("IND_7x7", "L3", "220n", 84, 70, 90),
        ("IND_7x7", "L4", "220n", 84, 82, 90),
        ("IND_7x7", "L5", "220n", 84, 94, 90),
        ("IND_7x7", "L6", "220n", 69, 108, 90),
        ("IND_7x7", "L7", "220n", 69, 120, 90),
        ("CAP_7343", "C5", "470u", 104, 120, 0),
        ("CAP_7343", "C6", "470u", 113, 120, 0),
        ("CAP_7343", "C7", "470u", 122, 120, 0),
        ("CAP_7343", "C8", "470u", 146, 120, 0),
        ("CAP_7343", "C9", "470u", 155, 120, 0),
        # BIOS + RTC + Systemtakt
        ("SOIC8", "U19", "W25Q256JW", 168, 48, 0),
        ("XTAL_3215", "Y1", "32.768k", 176, 48, 0),
        ("XTAL_3225", "Y2", "48M", 183, 48, 0),
        ("COIN_ML1220", "BT1", "ML1220", 223, 133, 90),
        # Systemwandler oben links neben dem Sockel
        ("QFN20_3x4", "U4", "5V Buck", 98, 38, 0),
        ("QFN20_3x4", "U5", "3V3 Buck", 109, 38, 0),
        ("QFN20_3x4", "U9", "3V3_ALW", 120, 38, 0),
        ("DFN6_2x2", "U6", "1V8", 129, 38, 0),
        ("DFN6_2x2", "U7", "1V05_TB", 137, 38, 0),
        ("DFN6_2x2", "U8", "0V88_TB", 145, 38, 0),
        ("DFN6_2x2", "U18", "1V1_MEM", 153, 38, 0),
        ("IND_4x4", "L9", "1u", 98, 44, 0),
        ("IND_4x4", "L10", "1u", 109, 44, 0),
        ("IND_4x4", "L11", "1u", 120, 44, 0),
        ("IND_4x4", "L12", "470n", 129, 44, 0),
        ("IND_4x4", "L13", "470n", 137, 44, 0),
        ("IND_4x4", "L14", "470n", 145, 44, 0),
        ("IND_4x4", "L15", "470n", 153, 44, 0),
        # Linke Kante (wie 850 G7): USB-A, Klinke; Audio-Codec
        ("USBA3_TH", "J_USBA1", "USB-A 5G", 40, 60, 90),
        ("SOT23-5", "U32", "VBUS-SW", 58, 60, 0),
        ("TRRS_35", "J_AUX", "Klinke", 38, 84, 90),
        ("QFN48_6x6", "U39", "ALC256", 60, 98, 0),
        # Rechte Kante (hinten->vorn, wie Foto des Originals):
        # Ladeport (Barrel-Position), USB-A, HDMI, 2x USB-C TB4
        ("USBC_24", "J_PWR", "USB-C Ladeport 100W", 352, 42, 270),
        ("USBA3_TH", "J_USBA2", "USB-A 5G", 352, 58, 270),
        ("HDMI_A", "J_HDMI", "HDMI 2.1", 350, 74, 270),
        ("USBC_24", "J_TB0", "USB-C TB4", 352, 90, 270),
        ("USBC_24", "J_TB1", "USB-C TB4", 352, 102, 270),
        ("BGA96_9x9", "U44", "TPS65987D Ladeport", 330, 40, 0),
        ("SOIC8", "U45", "PD2-Cfg", 318, 40, 0),
        ("SOT23-5", "U33", "VBUS-SW", 332, 52, 0),
        ("TSSOP24", "U36", "TPD12S016", 332, 74, 90),
        ("BGA_10x9_JHL8540", "U23", "JHL8540 TB4", 330, 94, 0),
        ("BGA96_9x9", "U1", "TPS65988 PD", 322, 108, 0),
        ("SOIC8", "U2", "PD-Cfg", 308, 108, 0),
        # Laderegler unten rechts
        ("QFN32_4x4", "U3", "BQ25731", 287, 124, 0),
        ("R_2512", "R2", "10m", 296, 124, 0),
        ("R_2512", "R1", "10m", 305, 124, 0),
        ("PowerPAK_1212", "Q5", "BATFET", 313, 124, 0),
        ("PowerPAK_1212", "Q1", "SiSS22DN", 285, 136, 0),
        ("PowerPAK_1212", "Q2", "SiSS22DN", 292, 136, 0),
        ("IND_7x7", "L1", "3u3", 300, 136, 0),
        ("PowerPAK_1212", "Q3", "SiSS22DN", 309, 136, 0),
        ("PowerPAK_1212", "Q4", "SiSS22DN", 316, 136, 0),
        ("R_0603", "RT3", "NTC CHG", 287, 130, 0),
        ("CAP_7343", "C1", "330u", 250, 138, 0),
        ("CAP_7343", "C2", "330u", 259, 138, 0),
        ("CAP_7343", "C3", "330u", 268, 138, 0),
        ("CAP_7343", "C4", "330u", 277, 138, 0),
        # Obere Kante: eDP, Webcam, Backlight, Luefter
        ("FPC40_05", "J_EDP", "eDP-Panel", 183, 35, 0),
        ("FPC6_05", "J_CAM", "Webcam", 203, 35, 0),
        ("SOT23-5", "U37", "VLCD-SW", 212, 40, 0),
        ("TSSOP16EP", "U38", "MP3389 BL", 221, 42, 0),
        ("IND_4x4", "L8", "10u", 230, 42, 0),
        ("SMA_DIODE", "D1", "SS3P4", 212, 46, 0),
        ("CONN_FAN4", "J_FAN1", "Luefter L", 78, 35, 0),
        ("CONN_FAN4", "J_FAN2", "Luefter R", 290, 35, 0),
        # Untere Kante: Akku, Tastatur, Touchpad, Lautsprecher, EC
        ("CONN_BAT8_2mm", "J_BAT", "HP-Akku 3S 56Wh", 195, 138, 0),
        ("FPC30_05", "J_KB", "HP-Tastatur", 154, 137, 0),
        ("FPC8_05", "J_TP", "HP-Clickpad", 115, 137, 0),
        ("FPC6_05", "J_LID", "Lid-Sensor", 100, 137, 0),
        ("CONN_SPK2", "J_SPKL", "Spk L", 52, 138, 0),
        ("CONN_SPK2", "J_SPKR", "Spk R", 276, 131, 0),
        ("LQFP128_14x14", "U41", "IT5570E EC", 135, 131, 0),
        ("SOIC8", "U42", "EC-Flash", 152, 131, 0),
        ("SOT23-5", "U21", "SSD1-SW", 277, 111, 0),
        ("SOT23-5", "U22", "SSD2-SW", 277, 104, 0),
        ("R_0603", "RT1", "NTC CPU", 163, 90, 0),
        ("R_0603", "RT2", "NTC VRM", 90, 48, 0),
        # Befestigung (Raster am 850-G7-Chassis final ausmessen!)
        ("MTG_M2_5", "H1", "", 28, 33, 0),
        ("MTG_M2_5", "H2", "", 160, 33, 0),
        ("MTG_M2_5", "H3", "", 345, 33, 0),
        ("MTG_M2_5", "H4", "", 30, 138, 0),
        ("MTG_M2_5", "H5", "", 240, 139, 0),
        ("MTG_M2_5", "H6", "", 274, 80, 0),
        ("MTG_M2_5", "H7", "", 28, 105, 0),
        ("MTG_M2_5", "H8", "", 300, 33, 0),
        # Bestueckung Unterseite (B.Cu): Entkopplungsbaenke unter dem Sockel
        ("R_0603", "C20", "22u", 112, 72, 0, "B"),
        ("R_0603", "C21", "22u", 122, 72, 0, "B"),
        ("R_0603", "C22", "22u", 132, 72, 0, "B"),
        ("R_0603", "C23", "22u", 142, 72, 0, "B"),
        ("R_0603", "C24", "22u", 112, 80, 0, "B"),
        ("R_0603", "C25", "22u", 122, 80, 0, "B"),
        ("R_0603", "C26", "22u", 132, 80, 0, "B"),
        ("R_0603", "C27", "22u", 142, 80, 0, "B"),
        ("R_0603", "C28", "22u", 112, 88, 0, "B"),
        ("R_0603", "C29", "22u", 122, 88, 0, "B"),
        ("R_0603", "C30", "22u", 132, 88, 0, "B"),
        ("R_0603", "C31", "22u", 142, 88, 0, "B"),
        ("R_0603", "C32", "22u", 104, 96, 0, "B"),
        ("R_0603", "C33", "22u", 114, 96, 0, "B"),
        ("R_0603", "C34", "22u", 124, 96, 0, "B"),
        ("R_0603", "C35", "22u", 104, 64, 0, "B"),
        ("R_0603", "C36", "22u", 114, 64, 0, "B"),
        ("R_0603", "C37", "22u", 124, 64, 0, "B"),
        # Schienen-Entkopplung (B.Cu, unter DIMM-/Wandlerbereich)
        ("R_0603", "C40", "10u", 170, 60, 0, "B"),
        ("R_0603", "C41", "10u", 178, 60, 0, "B"),
        ("R_0603", "C42", "10u", 186, 60, 0, "B"),
        ("R_0603", "C43", "10u", 194, 60, 0, "B"),
        ("R_0603", "C44", "10u", 202, 60, 0, "B"),
        ("R_0603", "C45", "10u", 210, 60, 0, "B"),
        ("R_0603", "C46", "10u", 218, 60, 0, "B"),
        ("R_0603", "C47", "10u", 226, 60, 0, "B"),
        ("R_0603", "C48", "10u", 234, 60, 0, "B"),
        ("R_0603", "C49", "10u", 242, 60, 0, "B"),
        ("R_0603", "C52", "100n", 170, 68, 0, "B"),
        ("R_0603", "C53", "100n", 178, 68, 0, "B"),
        ("R_0603", "C54", "100n", 186, 68, 0, "B"),
        ("R_0603", "C55", "100n", 194, 68, 0, "B"),
        ("R_0603", "C56", "100n", 202, 68, 0, "B"),
        ("R_0603", "C57", "100n", 210, 68, 0, "B"),
        ("R_0603", "C58", "100n", 218, 68, 0, "B"),
        ("R_0603", "C59", "100n", 226, 68, 0, "B"),
        ("R_0603", "C60", "100n", 234, 68, 0, "B"),
        ("R_0603", "C61", "100n", 242, 68, 0, "B"),
        # ESD-Arrays (B.Cu, direkt hinter den Buchsen)
        ("DFN6_2x2", "U50", "ESD TB0-L1", 344, 86, 0, "B"),
        ("DFN6_2x2", "U51", "ESD TB0-L2", 344, 92, 0, "B"),
        ("DFN6_2x2", "U52", "ESD TB1-L1", 344, 98, 0, "B"),
        ("DFN6_2x2", "U53", "ESD TB1-L2", 344, 104, 0, "B"),
        ("DFN6_2x2", "U54", "ESD USBA1", 46, 60, 0, "B"),
        ("DFN6_2x2", "U55", "ESD USBA2", 344, 56, 0, "B"),
        ("DFN6_2x2", "U56", "ESD HDMI-1", 342, 70, 0, "B"),
        ("DFN6_2x2", "U57", "ESD HDMI-2", 342, 76, 0, "B"),
        ("DFN6_2x2", "U58", "ESD CC", 344, 110, 0, "B"),
        ("DFN6_2x2", "U59", "ESD TB-USB2", 350, 80, 0, "B"),
        ("DFN6_2x2", "U60", "ESD A-USB2", 46, 68, 0, "B"),
        # USB2-Chokes + Straps (B.Cu)
        ("R_0603", "FL1", "CMC Webcam", 203, 40, 0, "B"),
        ("R_0603", "FL2", "CMC WLAN", 292, 52, 0, "B"),
        ("R_0603", "R10", "10k", 60, 40, 0, "B"),
        ("R_0603", "R11", "10k", 60, 46, 0, "B"),
        ("R_0603", "R12", "10k", 60, 52, 0, "B"),
        ("R_0603", "R13", "10k", 60, 58, 0, "B"),
        ("R_0603", "R14", "10k", 60, 64, 0, "B"),
        ("R_0603", "R15", "10k", 60, 70, 0, "B"),
    ]

    lib_board = pcb.build_library()
    extras = []
    # Platinenumriss 340 x 112 (EliteBook-850-G7-Innenraum, final ausmessen)
    X0, Y0, X1, Y1 = 25, 30, 365, 142
    extras += [pcb.gr_line(X0, Y0, X1, Y0), pcb.gr_line(X1, Y0, X1, Y1),
               pcb.gr_line(X1, Y1, X0, Y1), pcb.gr_line(X0, Y1, X0, Y0)]
    # Zonen
    all_pts = [(X0, Y0), (X1, Y0), (X1, Y1), (X0, Y1)]
    extras.append(pcb.zone(1, "GND", "In2.Cu", all_pts, "GND1"))
    extras.append(pcb.zone(1, "GND", "In5.Cu", all_pts, "GND2"))
    extras.append(pcb.zone(1, "GND", "B.Cu", all_pts, "GND-Bottom"))
    extras.append(pcb.zone(2, "+VSYS", "In3.Cu",
                           [(180, 30), (365, 30), (365, 142), (180, 142)], "VSYS"))
    extras.append(pcb.zone(2, "+VSYS", "In3.Cu",
                           [(25, 30), (115, 30), (115, 125), (25, 125)], "VSYS-VRM"))
    extras.append(pcb.zone(3, "+5V", "In4.Cu",
                           [(150, 30), (270, 30), (270, 80), (150, 80)], "5V"))
    extras.append(pcb.zone(4, "+3V3", "In4.Cu",
                           [(25, 30), (150, 30), (150, 142), (25, 142)], "3V3"))
    extras.append(pcb.zone(4, "+3V3", "In4.Cu",
                           [(270, 30), (365, 30), (365, 142), (270, 142)], "3V3-IO"))
    extras.append(pcb.zone(5, "+VDDCR_CPU", "In1.Cu",
                           [(95, 55), (160, 55), (160, 112), (95, 112)], "VDDCR_CPU"))
    extras.append(pcb.zone(6, "+VDDCR_SOC", "In1.Cu",
                           [(75, 60), (93, 60), (93, 105), (75, 105)], "VDDCR_SOC"))
    # Routing-Korridore (Hauptsignale, Feinabgleich siehe docs/layout.md)
    for i in range(4):  # PCIe P0 -> SSD1 (vertikal bei x=248)
        extras.append(pcb.diff_pair(160, 88 + i * 1.5, 240, 66 + i * 1.2, "In6.Cu"))
    for i in range(4):  # PCIe P2 -> JHL8540
        extras.append(pcb.diff_pair(160, 58 + i * 1.5, 322, 90 + i * 0.8, "In6.Cu"))
    for i in range(4):  # HDMI TMDS -> Buchse
        extras.append(pcb.diff_pair(160, 100 + i * 1.5, 342, 72 + i * 0.8, "F.Cu"))
    for i in range(4):  # DDR-Korridor Kanal A (Beispielpaare)
        extras.append(pcb.diff_pair(160, 70 + i * 1.5, 178, 58 + i * 1.2, "In1.Cu"))
    for i in range(2):  # DP0/DP1 -> JHL8540 DP-IN
        extras.append(pcb.diff_pair(160, 64 + i * 1.5, 324, 90 + i * 1, "In6.Cu"))
    # Ladepfad: J_PWR -> BQ25731 (breite VBUS_IN-Trasse, 2x 2mm)
    extras.append(pcb.segment(348, 46, 300, 118, 2.0, "F.Cu"))
    extras.append(pcb.segment(345.6, 46, 297.6, 118, 2.0, "F.Cu"))
    # GND-Stitching-Vias (Raster 15mm, Sockel- und Randzonen ausgespart)
    yv = 36
    while yv < 140:
        xv = 32
        while xv < 362:
            in_socket = 92 < xv < 165 and 40 < yv < 118
            in_edge = xv > 336 or xv < 44
            in_dimm = 158 < xv < 238 and 50 < yv < 124
            in_ssd = 228 < xv < 300 and 34 < yv < 122
            if not (in_socket or in_edge or in_dimm or in_ssd):
                extras.append(pcb.via(xv, yv, net=1))
            xv += 15
        yv += 13
    # Beschriftungen
    extras.append(pcb.gr_text("Laptop-Mainboard fuer HP EliteBook 850 G7 - Rev B", 195, 26, "F.SilkS", 3))
    extras.append(pcb.gr_text("AM5 - Kuehlerzone 100x75mm freihalten", 130, 82, "Cmts.User", 2))
    extras.append(pcb.gr_text("HP-Akkuschacht (3S 56Wh) unterhalb", 195, 147, "Cmts.User", 2))
    extras.append(pcb.gr_text("Umriss + Lochbild am realen 850-G7-Chassis verifizieren (docs/elitebook.md)", 195, 152, "Cmts.User", 1.5))

    board_text, netmap = pcb.board_file(PL, lib_board, extras)
    write(os.path.join(KICAD, "laptop-mainboard.kicad_pcb"), board_text)
    print(f"  Board-Netze: {len(netmap)}")

    # Stueckliste
    bom_path = os.path.join(DOCS, "bom.csv")
    with open(bom_path, "w") as fh:
        fh.write("Referenz;Wert;Beschreibung;Hersteller-Teilenummer;Footprint\n")
        for c in all_comps:
            fh.write(f"{c.ref};{c.value};{c.desc};{c.mpn};"
                     f"{c.fp.replace('laptop_mainboard:', '')}\n")
    print(f"  docs/bom.csv  ({len(all_comps)} Positionen)")
    print("Fertig.")


if __name__ == "__main__":
    main()

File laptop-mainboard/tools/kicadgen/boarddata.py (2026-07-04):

"""Bauteil-, Pin- und Netzdefinitionen aller Schaltplanblaetter.

Pin-Tupel: (Name, Seite L/R, Typ, Netz)  — Typ-Kuerzel siehe ET.
Busse nutzen KiCad-Syntax NAME[msb:0]; Member heissen NAME<n>.
"""
from .sch import Comp

ET = {"pi": "power_in", "po": "power_out", "i": "input", "o": "output",
      "b": "bidirectional", "p": "passive"}


def P(name, side, t, net):
    return (name, side, ET[t], net)


def cols(specs, y0=45.0, gap=17.78):
    """Spaltenweise Auto-Platzierung: specs = [(x, [comps]), ...]."""
    placed = []
    for x, comps in specs:
        y = y0
        for c in comps:
            cy = round((y + c.height / 2) / 1.27) * 1.27
            placed.append((c, x, cy))
            y = cy + c.height / 2 + gap
    return placed


FP = "laptop_mainboard:"

# ----------------------------------------------------------------------------
# Blatt 3: CPU-Sockel AM5
# ----------------------------------------------------------------------------

def cpu_socket():
    pins = [
        # --- Versorgung (links oben) ---
        P("VDDCR_CPU", "L", "pi", "+VDDCR_CPU"),
        P("VDDCR_SOC", "L", "pi", "+VDDCR_SOC"),
        P("VDD_MISC_1V8", "L", "pi", "+1V8"),
        P("VDDIO_MEM_1V1", "L", "pi", "+1V1_MEM"),
        P("VDD_1V8", "L", "pi", "+1V8"),
        P("VDD_3V3", "L", "pi", "+3V3"),
        P("VDD_3V3_S5", "L", "pi", "+3V3_ALW"),
        P("VDD_BT_RTC", "L", "pi", "VDD_RTC"),
        P("GND", "L", "pi", "GND"),
        # --- Speicher Kanal A ---
        P("MA_CA[13:0]", "L", "o", "MA_CA[13:0]"),
        P("MA_CK_T", "L", "o", "MA_CK_T"),
        P("MA_CK_C", "L", "o", "MA_CK_C"),
        P("MA_CS[1:0]", "L", "o", "MA_CS[1:0]"),
        P("MA_DQ[31:0]", "L", "b", "MA_DQ[31:0]"),
        P("MA_DQS_T[3:0]", "L", "b", "MA_DQS_T[3:0]"),
        P("MA_DQS_C[3:0]", "L", "b", "MA_DQS_C[3:0]"),
        P("MA_ALERT#", "L", "i", "MA_ALERT#"),
        P("MA_RESET#", "L", "o", "MA_RESET#"),
        # --- Speicher Kanal B ---
        P("MB_CA[13:0]", "L", "o", "MB_CA[13:0]"),
        P("MB_CK_T", "L", "o", "MB_CK_T"),
        P("MB_CK_C", "L", "o", "MB_CK_C"),
        P("MB_CS[1:0]", "L", "o", "MB_CS[1:0]"),
        P("MB_DQ[31:0]", "L", "b", "MB_DQ[31:0]"),
        P("MB_DQS_T[3:0]", "L", "b", "MB_DQS_T[3:0]"),
        P("MB_DQS_C[3:0]", "L", "b", "MB_DQS_C[3:0]"),
        P("MB_ALERT#", "L", "i", "MB_ALERT#"),
        P("MB_RESET#", "L", "o", "MB_RESET#"),
        # --- SPI-BIOS / eSPI / SMBus (links unten) ---
        P("SPI_CS#", "L", "o", "BIOS_CS#"),
        P("SPI_CLK", "L", "o", "BIOS_CLK"),
        P("SPI_MOSI", "L", "o", "BIOS_MOSI"),
        P("SPI_MISO", "L", "i", "BIOS_MISO"),
        P("ESPI_IO[3:0]", "L", "b", "ESPI_IO[3:0]"),
        P("ESPI_CLK", "L", "o", "ESPI_CLK"),
        P("ESPI_CS#", "L", "o", "ESPI_CS#"),
        P("ESPI_ALERT#", "L", "i", "ESPI_ALERT#"),
        P("ESPI_RESET#", "L", "o", "ESPI_RESET#"),
        P("SMB_SCL", "L", "b", "SPD_HSCL"),
        P("SMB_SDA", "L", "b", "SPD_HSDA"),
        # --- Steuerung / SVI3 / RTC ---
        P("PWR_BTN#", "L", "i", "PM_PWR_BTN#"),
        P("SYS_RESET#", "L", "i", "SYS_RESET#"),
        P("PWROK", "L", "i", "SYS_PWROK"),
        P("SLP_S3#", "L", "o", "SLP_S3#"),
        P("SLP_S5#", "L", "o", "SLP_S5#"),
        P("PROCHOT#", "L", "b", "PROCHOT#"),
        P("THERMTRIP#", "L", "o", "THERMTRIP#"),
        P("SVI3_SVC", "L", "o", "SVI3_SVC"),
        P("SVI3_SVD", "L", "b", "SVI3_SVD"),
        P("SVI3_SVT", "L", "i", "SVI3_SVT"),
        P("X32K_XI", "L", "p", "X32K_XI"),
        P("X32K_XO", "L", "p", "X32K_XO"),
        P("X48M_X1", "L", "p", "X48M_X1"),
        P("X48M_OSC", "L", "p", "X48M_OSC"),
        # --- PCIe (rechts) ---
        P("P0_TXP[3:0]", "R", "o", "NVME1_TXP[3:0]"),
        P("P0_TXN[3:0]", "R", "o", "NVME1_TXN[3:0]"),
        P("P0_RXP[3:0]", "R", "i", "NVME1_RXP[3:0]"),
        P("P0_RXN[3:0]", "R", "i", "NVME1_RXN[3:0]"),
        P("P1_TXP[3:0]", "R", "o", "NVME2_TXP[3:0]"),
        P("P1_TXN[3:0]", "R", "o", "NVME2_TXN[3:0]"),
        P("P1_RXP[3:0]", "R", "i", "NVME2_RXP[3:0]"),
        P("P1_RXN[3:0]", "R", "i", "NVME2_RXN[3:0]"),
        P("P2_TXP[3:0]", "R", "o", "TB_TXP[3:0]"),
        P("P2_TXN[3:0]", "R", "o", "TB_TXN[3:0]"),
        P("P2_RXP[3:0]", "R", "i", "TB_RXP[3:0]"),
        P("P2_RXN[3:0]", "R", "i", "TB_RXN[3:0]"),
        P("G0_TXP", "R", "o", None),
        P("G0_TXN", "R", "o", None),
        P("G0_RXP", "R", "i", None),
        P("G0_RXN", "R", "i", None),
        P("G1_TXP", "R", "o", None),
        P("G1_TXN", "R", "o", None),
        P("G1_RXP", "R", "i", None),
        P("G1_RXN", "R", "i", None),
        P("G2_TXP", "R", "o", "WIFI_PE_TXP"),
        P("G2_TXN", "R", "o", "WIFI_PE_TXN"),
        P("G2_RXP", "R", "i", "WIFI_PE_RXP"),
        P("G2_RXN", "R", "i", "WIFI_PE_RXN"),
        P("GPP_CLKP[5:0]", "R", "o", "PE_CLKP[5:0]"),
        P("GPP_CLKN[5:0]", "R", "o", "PE_CLKN[5:0]"),
        P("CLKREQ0#", "R", "i", "NVME1_CLKREQ#"),
        P("CLKREQ1#", "R", "i", "NVME2_CLKREQ#"),
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

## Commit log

2026-05-29 Velo Navi Schweiz – Bike-/E-Bike-Navigation (#1)
    * Velo Navi Schweiz: Bike-/E-Bike-Navigation mit Routenvorschlägen, Höhen-/Zeitberechnung und Tempo-Feedback
    - Routing über BRouter (OSM) mit Profilen Trekking/Rennvelo/Gravel/MTB + Alternativrouten
    - Physikbasierte Zeitberechnung inkl. Steigung und Velo-Typ (Velo / E-Bike 25 / E-Bike 45, Motor-Abregelung)
    - Routenbeschreibung (Strasse/Veloweg/Schotter/Wald/Trail), Höhenmeter und Höhenprofil
    - Ortssuche und Karten über swisstopo/geo.admin.ch, Leaflet-Karte
    - Feedback nach Fahrt kalibriert Tempo pro Velo-Typ (localStorage)
    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
2026-05-29 Live-Navigation, Sprachführung, GPS-Standort und PWA hinzufügen
    - Vollbild-Navigationsmodus mit Turn-by-Turn-Anweisungen (aus Routengeometrie abgeleitet)
    - Sprachausgabe auf Deutsch (Web Speech API) mit Vorankuendigungen
    - Live-GPS (watchPosition): Positionsmarker, Restroute, ETA/Restzeit/Distanz/Tempo
    - Automatisches Rerouting bei Routenabweichung (>40m)
    - Wake Lock haelt Display an, Kompass fuer Richtungspfeil
    - 'Mein Standort'-Button als Start (GPS + Reverse-Geocoding)
    - PWA: manifest, Service Worker (App-Shell offline), Icons, installierbar
    https://claude.ai/code/session_01TaZKzK2DkzCN9JsG17ijLb
2026-05-29 Bugfixes: Ziel/Start aus Texteingabe uebernehmen, Tausch behaelt Punkte, Karte setzt Punkt erst bei 1s Long-Press
    - Eingetippter Ort wird beim Verlassen des Feldes / Enter automatisch geokodiert und gesetzt (auch ohne Vorschlagsauswahl)
    - 'Routen berechnen' holt fehlende Punkte aus den Textfeldern nach
    - Tauschen behaelt beide Punkte korrekt
    - Kartenpunkt nur noch per 1-Sekunden-Long-Press (verhindert versehentliches Setzen beim Routenauswaehlen/Verschieben), mit visuellem Ring
    - Long-Press im Navi-Modus deaktiviert
2026-05-29 Long-Press auf 450ms verkuerzen und iOS-Auswahl-/Kopiermenue auf der Karte unterdruecken
    - Halte-Dauer 700ms -> 450ms (verhindert iOS-Text-Auswahlmenue)
    - -webkit-touch-callout/user-select none auf Karte
    - preventDefault auf mousedown, kurzes haptisches Feedback
    - SW-Cache auf v2 fuer Update
2026-07-03 Laptop-Mainboard: komplettes KiCad-Projekt (AM5 gesockelt, TB4, 2x2.5GbE)
    - 9 hierarchische Schaltplanblaetter: PD-Laden (TPS65988/BQ25731), VRM SVI3
    4+2 Phasen, AM5-Sockel chipsatzlos, 2x DDR5 SO-DIMM, 2x M.2 NVMe + WLAN,
    Thunderbolt 4 (JHL8540), 2x RTL8125BG, eDP/HDMI, Audio/SD/EC
    - PCB 330x115mm, 8 Lagen: kollisionsfreier Floorplan (112 Footprints inkl.
    LGA-1718-Raster und 262-Pin-SO-DIMM), GND-/Power-Zonen, Routing-Korridore
    - Python-Generator (tools/) erzeugt alle KiCad-8-Dateien deterministisch,
    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
    [01_power_pd.kicad_sch, 02_vrm_cpu.kicad_sch, 03_cpu_am5.kicad_sch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]
2026-07-03 Rev B: echte AM5-Pinbelegung, Kleinteile, EliteBook-850-G7-Format
    - AM5-Pinmap (1718 Pins, WikiChip/Wikimedia Public Domain) als CSV,
    Sockel-Footprint mit echten Padnamen und 1708 Signal-Netzen im Board
    - Blatt 10: MLCC-Baenke, 11 ESD-Arrays, USB2-Chokes, Straps; 48-MHz-Quarz;
    beidseitige Bestueckung (B.Cu) mit Kollisionspruefung pro Seite
    - Board 340x112mm im EliteBook-850-G7-Layout: USB-C-100W-PD an der
    Barrel-Jack-Position, TB4/HDMI/USB-A/RJ45 rechts, USB-A/Klinke links,
    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
    [01_power_pd.kicad_sch, 02_vrm_cpu.kicad_sch, 03_cpu_am5.kicad_sch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]
2026-07-04 Portlayout nach Fotos des Originalgeraets korrigiert
    - Rechte Kante hinten->vorn: USB-C-Ladeport 100W (Barrel-Position,
    eigener TPS65987D + Config-Flash, neues Blatt 07_ladeport), USB-A,
    HDMI, 2x USB-C Thunderbolt 4 nebeneinander (JHL8540)
    - Kein RJ45 (Original hat keines): Ethernet entfernt, G0/G1 Reserve
    - TPS65988 nur noch Source fuer die TB-Ports; breite VBUS_IN-Trasse
    vom Ladeport zum BQ25731
    - Interne Anschlusspositionen des Original-Mainboards (Nutzerfoto)
    als Referenztabelle in docs/elitebook.md dokumentiert
    - Doku, Blockdiagramm, BOM und Rendering aktualisiert
    Claude-Session: https://claude.ai/code/session_01E8mU1RUAv93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
    [01_power_pd.kicad_sch, 03_cpu_am5.kicad_sch, 04_memory.kicad_sch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]

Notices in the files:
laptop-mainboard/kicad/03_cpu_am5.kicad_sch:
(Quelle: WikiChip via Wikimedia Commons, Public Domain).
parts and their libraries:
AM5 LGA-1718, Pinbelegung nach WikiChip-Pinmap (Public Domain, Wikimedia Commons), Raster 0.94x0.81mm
